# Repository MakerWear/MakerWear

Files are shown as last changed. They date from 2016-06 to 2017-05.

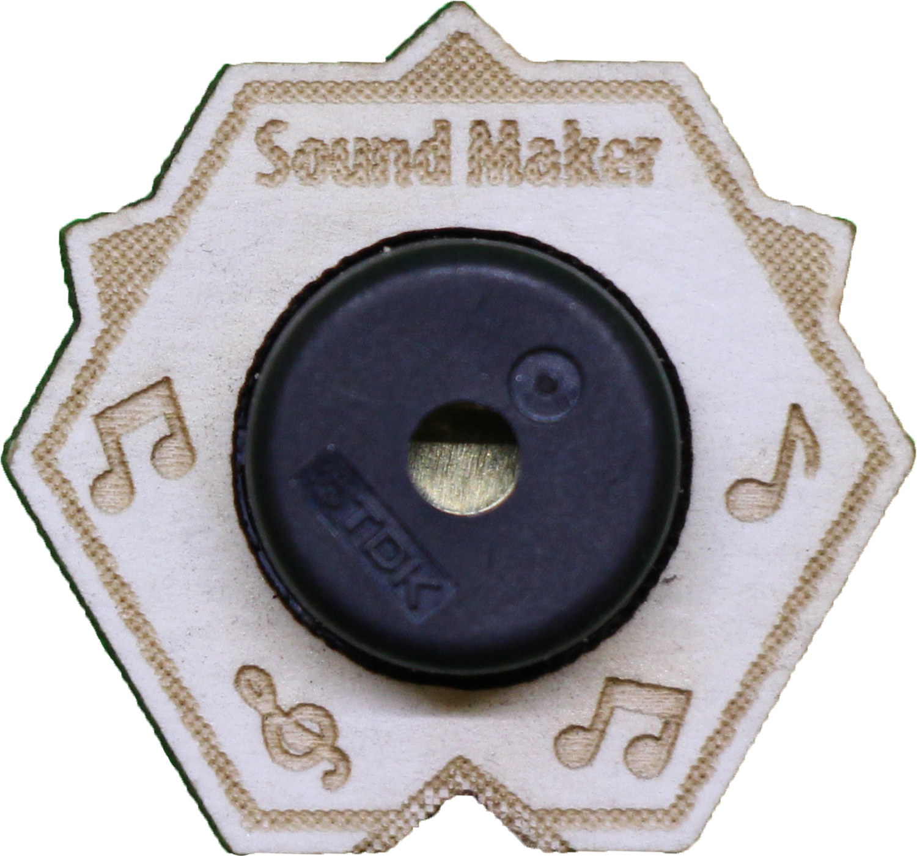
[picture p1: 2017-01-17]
Common/Wiki/images/Action/SoundMaker.png

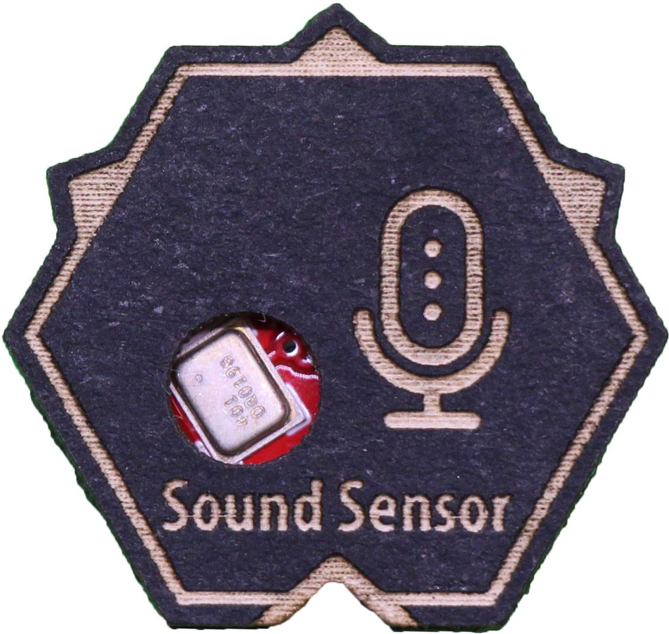
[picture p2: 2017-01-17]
Common/Wiki/images/Sensor/SoundSensor.png

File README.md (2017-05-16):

# MakerWear
MakerWear is a tangible and modular, wearable construction kit for young children that contains two parts: (1) a set of single-function, plug-and-play modules that could be combined to create complex interactive behaviors; (2) magnetic socket meshes that are pre-sewn into clothing that provides an easy method to attach and detach modules to clothes.

This repository contains all of the source files that are required to build or modify MakerWear modules in addition to the socket mesh.

# Repository Organization
For example, take the MultiColor Light as an example. Similar to almost all other modules, the MultiColor Light is a 1x3 module which means that it has one input and three outputs and requires two PCBs to build. The bottom PCB is found here: https://github.com/MakerWear/MakerWear/tree/master/Common/BasePCBs/1x3/Bottom and the Top PCB (along with the rest of the source files that are specifically designed for this module) is found here: https://github.com/MakerWear/MakerWear/tree/master/Modules/Action/MultiColorLight

The ComponentList.xlsx contains all of the components and links to the vendors from which you can buy them. the .brd file (board layout) should always be next the the .sch file (board schematics).

Each module has a microcontroller which could be programmed using an Arduino. the arduino source file is inside the https://github.com/MakerWear/MakerWear/tree/master/Modules/Action/MultiColorLight/ArduinoCodes folder. and finally, there is an illustrator file which is used to cut/etch a piece of colored cardboard (e.g. white, red, black, blue for action, power, sensor and modifier) using a laser cutter.

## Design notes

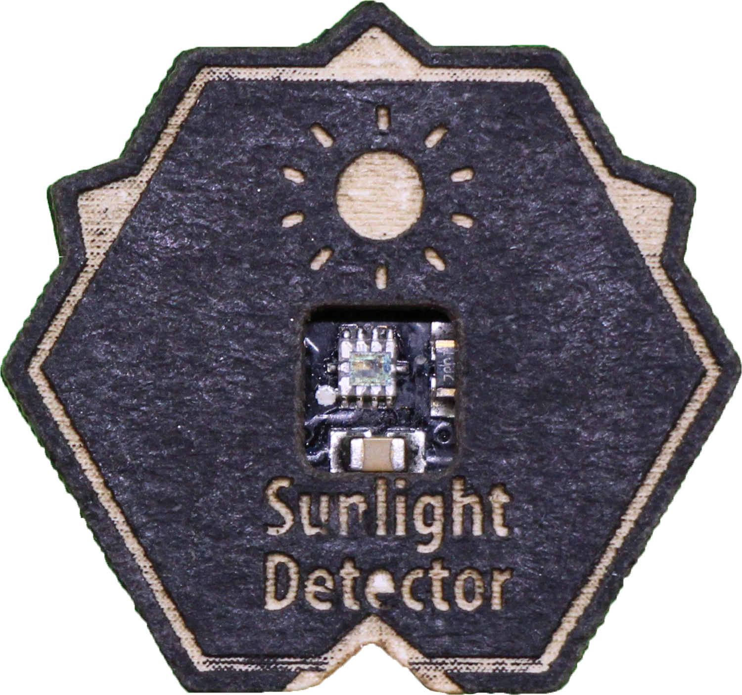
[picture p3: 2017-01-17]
Common/Wiki/images/Sensor/SunlightDetector.png

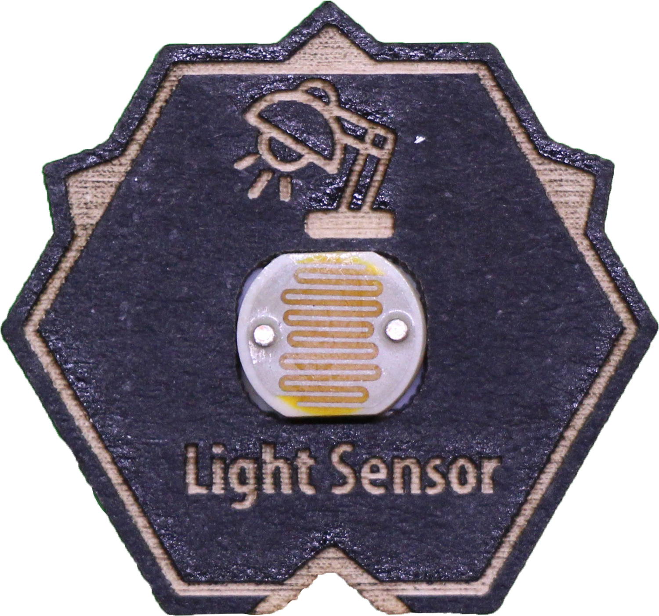
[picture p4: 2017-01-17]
Common/Wiki/images/Sensor/LightSensor.png

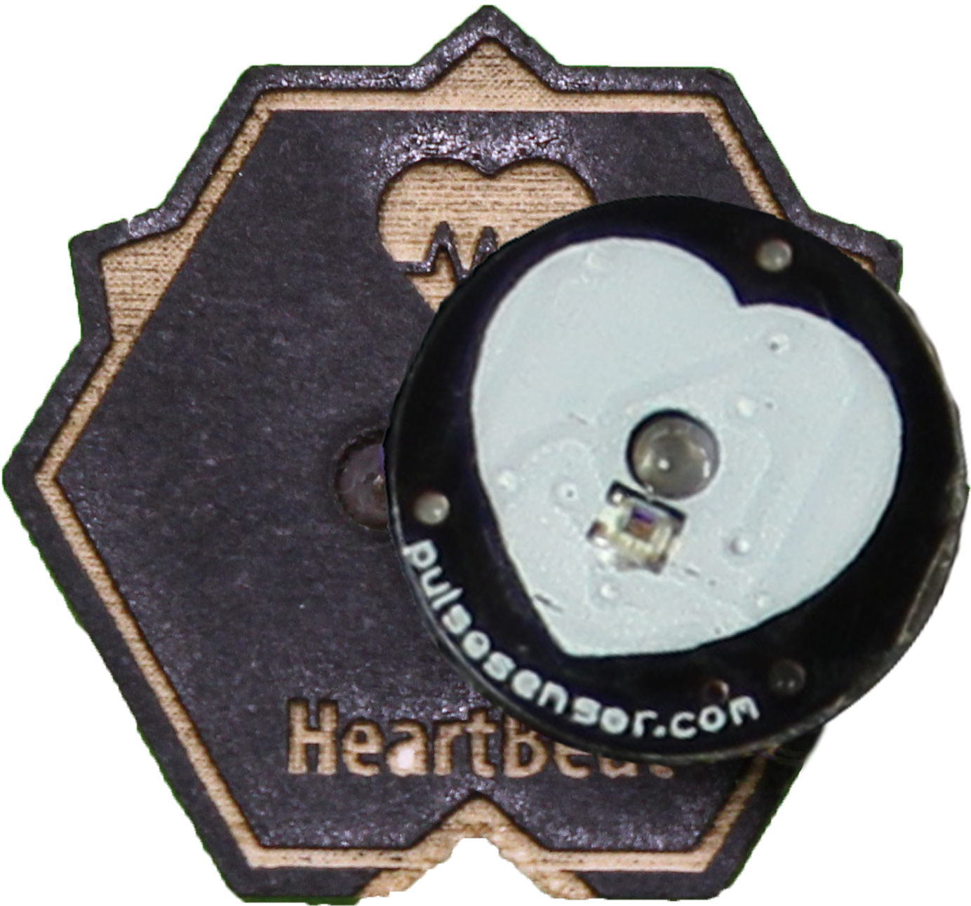
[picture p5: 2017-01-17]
Common/Wiki/images/Sensor/HeartBeatDetector_v3.png

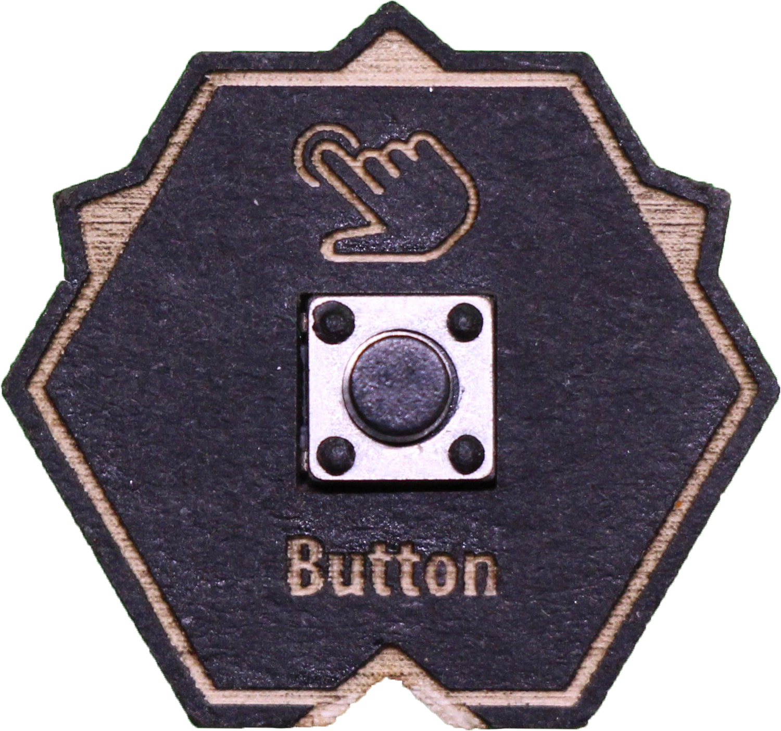
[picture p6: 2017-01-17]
Common/Wiki/images/Sensor/Button.png

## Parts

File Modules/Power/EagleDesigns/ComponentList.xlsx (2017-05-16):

Name | Link | Dimensions | Count | Price
680Ω Resistor | https://www.digikey.com/short/3n01ht | 0603 | 1
SPDT Slide Switch | https://www.sparkfun.com/products/9609 | Through Hole | 1
Small Red LED | https://www.digikey.com/short/3n01cn | 3mm | 1
Shield Finger Contact Spring | http://www.digikey.com/short/3zzmh1 | SMD | 9
3x1 Pin Header | http://www.digikey.com/short/3zzh43 | 2.54mm Pitch | 1

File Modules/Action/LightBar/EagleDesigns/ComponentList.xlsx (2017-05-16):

Name | Link | Dimensions | Count | Price
Rectangular Yellow LED | https://www.digikey.com/short/3n021c | 5x2mm | 2
Rectangular Red LED | https://www.digikey.com/short/3n021z | 5x2mm | 1
Rectangular Green LED | https://www.digikey.com/short/3n0214 | 5x2mm | 1
100Ω SMD Resistor | https://www.digikey.com/short/3n0w5w | 0603 | 4
ATtiny85-20PU | http://www.digikey.com/short/3zphbw | DIP | 1
Shield Finger Contact Spring | http://www.digikey.com/short/3zzmh1 | SMD | 6
1MΩ SMD Resistor | http://www.digikey.com/short/35mdtn | 0603 | 1
4x1 Pin Header | http://www.digikey.com/short/3zzh43 | 2.54mm Pitch | 1

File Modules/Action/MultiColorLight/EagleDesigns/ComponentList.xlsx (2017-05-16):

Name | Link | Dimensions | Count | Price
RGB LED Diffused Common Cathode | https://www.sparkfun.com/products/9264 | 5mm | 1
680Ω SMD Resistor | https://www.digikey.com/short/3n0w0z | 0603 | 1
100Ω SMD Resistor | https://www.digikey.com/short/3n0w5w | 0603 | 2
ATtiny85-20PU | http://www.digikey.com/short/3zphbw | DIP | 1
Shield Finger Contact Spring | http://www.digikey.com/short/3zzmh1 | SMD | 6
1MΩ SMD Resistor | http://www.digikey.com/short/35mdtn | 0603 | 1
4x1 Pin Header | http://www.digikey.com/short/3zzh43 | 2.54mm Pitch | 1

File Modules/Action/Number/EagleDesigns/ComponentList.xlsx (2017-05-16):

Name | Link | Dimensions | Count | Price
7-Segment | http://www.digikey.com/short/3zpcvw | 10x7.3x3.75mm | 1
300Ω SMD Resistor | https://www.digikey.com/short/3n0n83 | 0603 | 1
ATmega328P-AU-ND | http://www.digikey.com/short/3pr0nz | 32TQFP | 1
Shield Finger Contact Spring | http://www.digikey.com/short/3zzmh1 | SMD | 6
1MΩ SMD Resistor | http://www.digikey.com/short/35mdtn | 0603 | 1
4x1 Pin Header | http://www.digikey.com/short/3zzh43 | 2.54mm Pitch | 1

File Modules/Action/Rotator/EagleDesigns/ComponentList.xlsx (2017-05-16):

Name | Link | Dimensions | Count | Price
Nano Servo Motor | https://www.sparkfun.com/products/11882 | 18.6x7.6x15.5mm | 1
ATmega328P-AU-ND | http://www.digikey.com/short/3pr0nz | 32TQFP | 1
Shield Finger Contact Spring | http://www.digikey.com/short/3zzmh1 | SMD | 6
1MΩ SMD Resistor | http://www.digikey.com/short/35mdtn | 0603 | 1
4x1 Pin Header | http://www.digikey.com/short/3zzh43 | 2.54mm Pitch | 1

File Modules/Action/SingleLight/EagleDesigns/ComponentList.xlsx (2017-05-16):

Name | Link | Dimensions | Count | Price
Diffused single-color LED | https://www.sparkfun.com/products/12062 | 5mm | 1
100Ω SMD Resistor | https://www.digikey.com/short/3n0w5w | 0603 | 1
ATtiny85-20PU | http://www.digikey.com/short/3zphbw | DIP | 1
Shield Finger Contact Spring | http://www.digikey.com/short/3zzmh1 | SMD | 6
1MΩ SMD Resistor | http://www.digikey.com/short/35mdtn | 0603 | 1
4x1 Pin Header | http://www.digikey.com/short/3zzh43 | 2.54mm Pitch | 1

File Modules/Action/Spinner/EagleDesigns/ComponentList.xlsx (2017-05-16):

Name | Link | Dimensions | Count | Price
Uxcell DC Motor | https://amzn.com/B00BG8V144 |  | 1
10Ω SMD Resistor | https://www.digikey.com/short/3n0n9h | 0603 | 1
ATtiny85-20PU | http://www.digikey.com/short/3zphbw | DIP | 1
Shield Finger Contact Spring | http://www.digikey.com/short/3zzmh1 | SMD | 6
1MΩ SMD Resistor | http://www.digikey.com/short/35mdtn | 0603 | 1
4x1 Pin Header | http://www.digikey.com/short/3zzh43 | 2.54mm Pitch | 1

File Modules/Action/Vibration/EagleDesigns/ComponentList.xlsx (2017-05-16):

Name | Link | Dimensions | Count | Price
Vibrating Mini Motor Disc | https://www.adafruit.com/product/1201 | 10mm | 1
4.7Ω SMD Resistor | https://www.digikey.com/short/3n0d85 | 0603 | 1
ATtiny85-20PU | http://www.digikey.com/short/3zphbw | DIP | 1
Shield Finger Contact Spring | http://www.digikey.com/short/3zzmh1 | SMD | 6
1MΩ SMD Resistor | http://www.digikey.com/short/35mdtn | 0603 | 1
4x1 Pin Header | http://www.digikey.com/short/3zzh43 | 2.54mm Pitch | 1

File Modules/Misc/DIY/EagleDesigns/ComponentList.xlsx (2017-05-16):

Name | Link | Dimensions | Count | Price
Op-Amp (Rail-to-Rail) | http://www.digikey.com/short/3zp31d | SMD | 1
Shield Finger Contact Spring | http://www.digikey.com/short/3zzmh1 | SMD | 6
4x1 Pin Header | http://www.digikey.com/short/3zzh43 | 2.54mm Pitch | 1
Tiny Breadboard | https://www.adafruit.com/products/2463 | 18x13mm | 1

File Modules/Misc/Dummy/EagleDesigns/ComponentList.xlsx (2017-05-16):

Name | Link | Dimensions | Count | Price
Shield Finger Contact Spring | http://www.digikey.com/short/3zzmh1 | SMD | 6
4x1 Pin Header | http://www.digikey.com/short/3zzh43 | 2.54mm Pitch | 1
3D Printed LEGO Piece

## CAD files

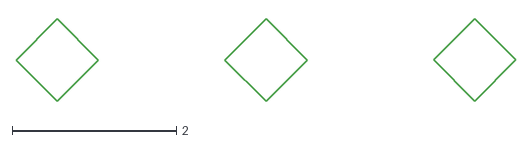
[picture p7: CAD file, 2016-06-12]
Common/BasePCBs/0x6/Bottom/Dimensions/dxf/0x6_bottom_tLayer.dxf
6.08 x 1.00

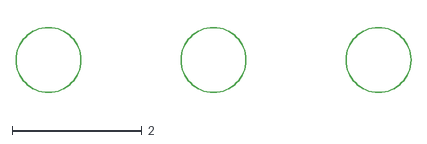
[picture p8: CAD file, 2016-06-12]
Common/BasePCBs/0x6/Top/Dimensions/dxf/0x6_top_pads(holes).dxf
6.08 x 1.00

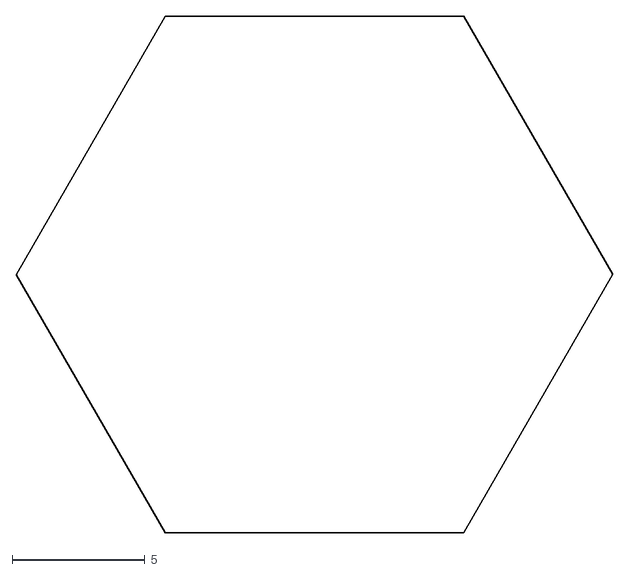
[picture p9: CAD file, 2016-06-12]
Common/BasePCBs/1x3/Bottom/Dimensions/dxf/0x6_bottom_board_outline(a).dxf
22.5 x 19.5

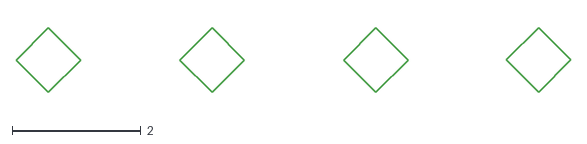
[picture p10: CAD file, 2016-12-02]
Common/BasePCBs/1x3/TopLarge/Dimensions/1x3Top_pads.dxf
8.61 x 1.00

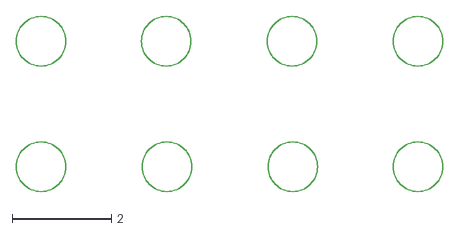
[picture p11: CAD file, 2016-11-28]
Common/BasePCBs/3x3/bottom/Dimensions/dxf/3x3Bottom_pads.dxf
8.61 x 3.53

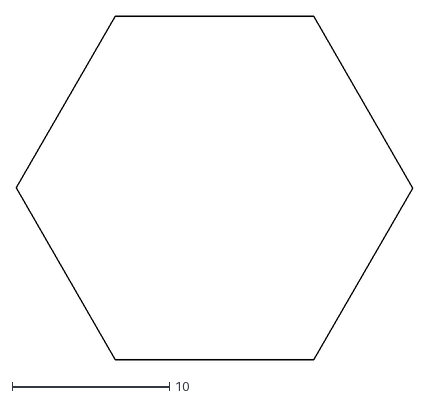
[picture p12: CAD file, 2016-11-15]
Common/BasePCBs/3x3/top/Dimensions/dxf/3x3Top_outline(b).dxf
25.2 x 21.8

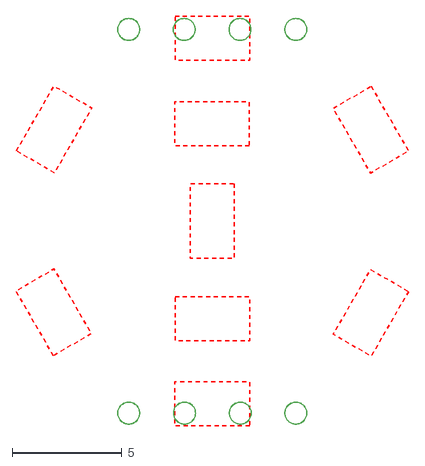
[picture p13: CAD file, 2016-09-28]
Common/BasePCBs/3x3Bottom/Dimensions/placements.dxf
17.9 x 18.7

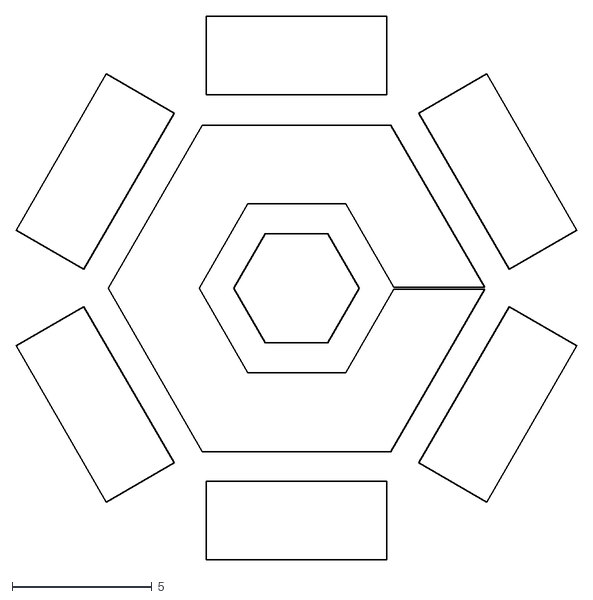
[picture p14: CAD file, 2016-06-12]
Common/BasePCBs/Socket/Dimensions/dxf/socket_bLayer.dxf
20.1 x 19.5

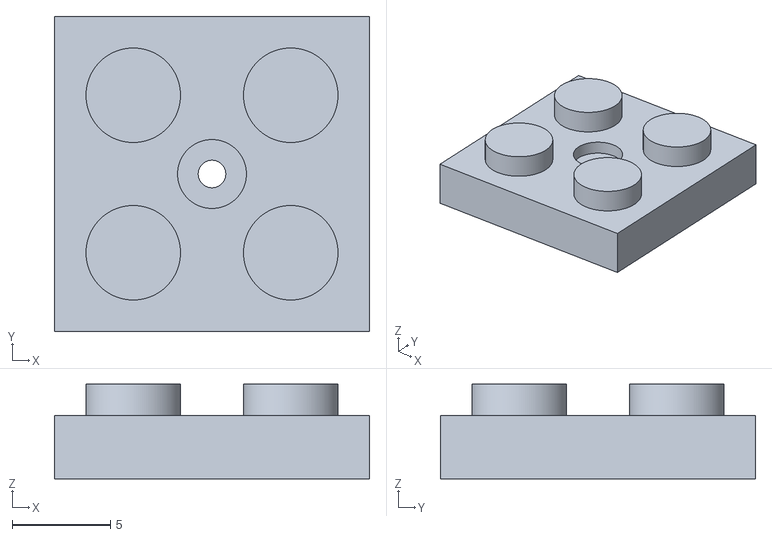
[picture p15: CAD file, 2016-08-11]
Modules/Action/Rotator/3DModels/LegoShaft.stl
16.0 x 16.0 x 4.80

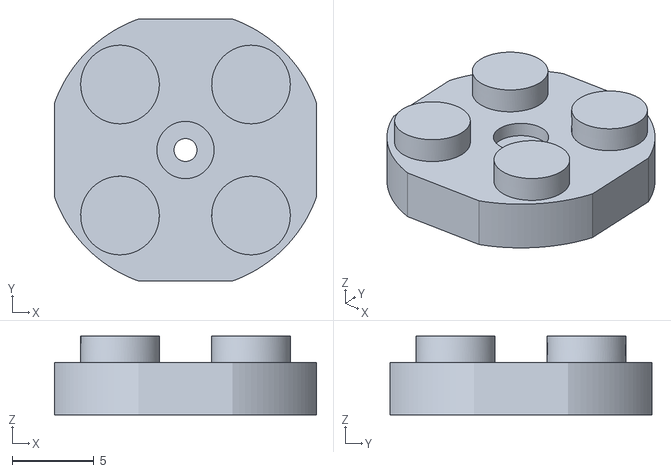
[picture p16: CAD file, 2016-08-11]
Modules/Misc/Dummy/3DModels/DummyLEGO.stl
16.0 x 16.0 x 4.80

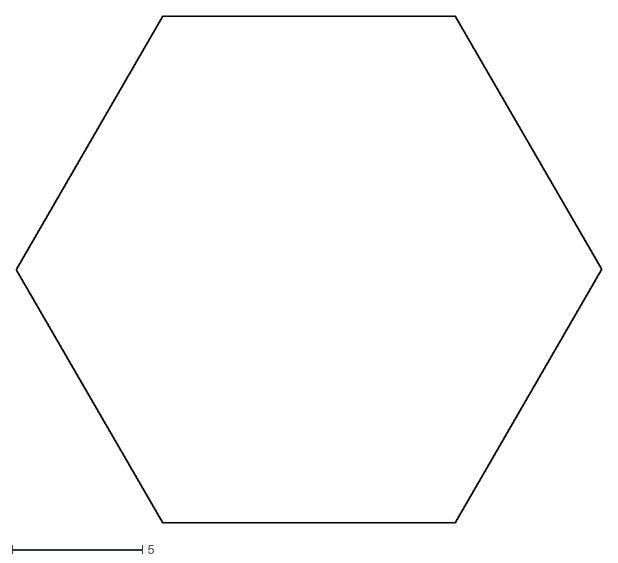
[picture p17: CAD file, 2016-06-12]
Common/BasePCBs/0x6/Bottom/Dimensions/dxf/0x6_bottom_board_outline(a).dxf
22.5 x 19.5

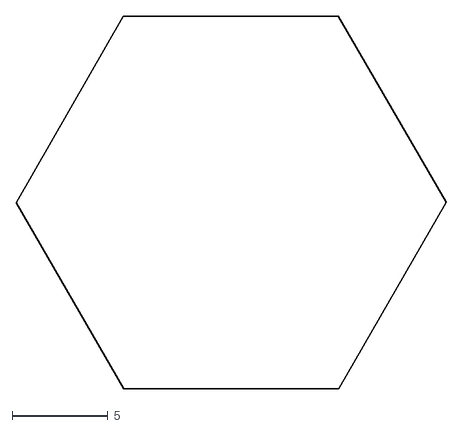
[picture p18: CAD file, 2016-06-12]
Common/BasePCBs/0x6/Top/Dimensions/dxf/0x6_top_board_outline(b).dxf
22.5 x 19.5

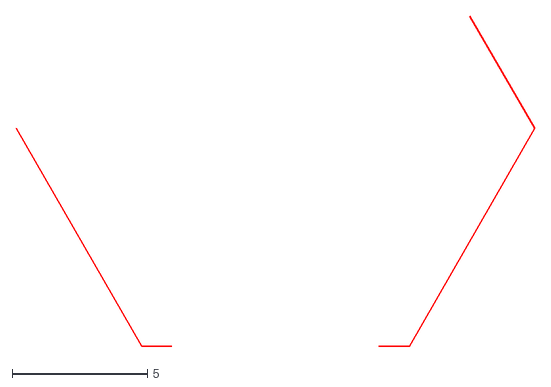
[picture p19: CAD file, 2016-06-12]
Common/BasePCBs/1x3/Bottom/Dimensions/dxf/1x3_bottom_tDoc.dxf
19.2 x 12.2

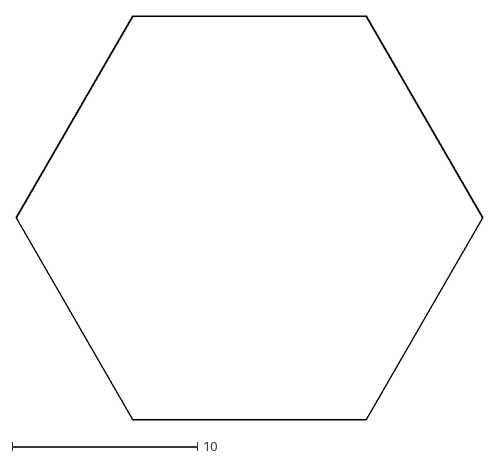
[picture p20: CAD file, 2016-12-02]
Common/BasePCBs/1x3/TopLarge/Dimensions/1x3Top_outline(a).dxf
25.2 x 21.8

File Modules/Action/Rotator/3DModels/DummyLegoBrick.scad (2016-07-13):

/*

 Basic Lego brick builder module for OpenScad by Jorg Janssen 2013 (CC BY-NC 3.0) 
 To use this in your own projects add:

 use <path_to_this_file/lego_brick_builder.scad>
 brick (length, width, height [,smooth]);

 Length and width are in standard lego brick dimensions. 
 Height is in flat brick heights, so for a normal lego brick height = 3.
 Add optional smooth = true for a brick without studs. 
 Use height = 0 to just put studs/knobs on top of other things.

 */
$fn = 150;
 
 // this is it:
brick(2,2,1);


// and this is how it's done:

FLU = 1.6; // Fundamental Lego Unit = 1.6 mm

BRICK_WIDTH = 5*FLU; // basic brick width
BRICK_HEIGHT = 6*FLU; // basic brick height
PLATE_HEIGHT = 2*FLU; // basic plate height
WALL_THICKNESS = FLU; // outer wall of the brick
STUD_RADIUS = 0*FLU; // studs are the small cylinders on top of the brick with the lego logo ('nopje' in Dutch)
STUD_HEIGHT = FLU; 
ANTI_STUD_RADIUS = 0.5*4.07*FLU;  // an anti stud is the hollow cylinder inside bricks that have length > 1 and width > 1
PIN_RADIUS = FLU; // a pin is the small cylinder inside bricks that have length = 1 or width = 1
SUPPORT_THICKNESS = 0.254; // support is the thin surface between anti studs, pins and walls, your printer might not print this thin, try thicker!
EDGE = 0.254; // this is the width and height of the bottom line edge of smooth bricks
CORRECTION = 0.1; // addition to each size, to make sure all parts connect by moving them a little inside each other

module brick(length = 4, width = 2, height = 3, smooth = false){

	// brick shell
	difference(){
		cube(size = [length*BRICK_WIDTH,width*BRICK_WIDTH,height*PLATE_HEIGHT]);
		translate([WALL_THICKNESS,WALL_THICKNESS,-WALL_THICKNESS])
		union(){
			cube(size = [length*BRICK_WIDTH-2*WALL_THICKNESS,width*BRICK_WIDTH-2*WALL_THICKNESS,height*PLATE_HEIGHT]);
			// stud inner holes, radius = pin radius
			if (!smooth) {
			
			}
			// small bottom line edge for smooth bricks
			else {
				translate([-WALL_THICKNESS-CORRECTION,-WALL_THICKNESS-CORRECTION,FLU-CORRECTION]) 
				difference() {
					cube([length*BRICK_WIDTH+2*CORRECTION,width*BRICK_WIDTH+2*CORRECTION,EDGE+CORRECTION]);
					translate([EDGE+CORRECTION,EDGE+CORRECTION,-CORRECTION])
					cube([length*BRICK_WIDTH-2*EDGE,width*BRICK_WIDTH-2*EDGE,EDGE+3*CORRECTION]); 
				}
			}
		}
	}
	// Studs
	if(!smooth){
		translate([STUD_RADIUS+WALL_THICKNESS,STUD_RADIUS+WALL_THICKNESS,height*PLATE_HEIGHT])
		for (y = [0:width-1]){
			for (x = [0:length-1]){
				translate ([x*BRICK_WIDTH,y*BRICK_WIDTH,-CORRECTION])
				difference(){
					cylinder(h=STUD_HEIGHT+CORRECTION, r=STUD_RADIUS);
					// Stud inner holes
					translate([0,0,-CORRECTION])
					cylinder(h=0.5*STUD_HEIGHT+CORRECTION,r=PIN_RADIUS);
				}
				// tech logo - disable this if your printer isn't capable of printing this small
				if ( length > width){
					translate([x*BRICK_WIDTH+0.8,y*BRICK_WIDTH-1.9,STUD_HEIGHT-CORRECTION])
					resize([1.2*1.7,2.2*1.7,0.254+CORRECTION])
					rotate(a=[0,0,90])
					import("tech.stl");
				}
				else {
					translate([x*BRICK_WIDTH-1.9,y*BRICK_WIDTH-0.8,STUD_HEIGHT-CORRECTION])
					resize([2.2*1.7,1.2*1.7,0.254+CORRECTION])
					import("tech.stl");				
				}				
				/* 
				// Alternative 2-square logo
				translate ([x*BRICK_WIDTH+CORRECTION,y*BRICK_WIDTH-CORRECTION,STUD_HEIGHT-CORRECTION])		
				cube([1,1,2*CORRECTION]);
				translate ([x*BRICK_WIDTH-0.9,y*BRICK_WIDTH-0.9,STUD_HEIGHT-CORRECTION])		
				cube([1,1,0.3]);
				*/				
			}
		}
	}
	// Pins x
	if (width == 1 && length > 1) {	
			for (x = [1:length-1]){
				translate([x*BRICK_WIDTH,0.5*BRICK_WIDTH,0])
				cylinder(h=height*PLATE_HEIGHT-WALL_THICKNESS+CORRECTION,r=PIN_RADIUS);
				// Supports
				if (height > 1) {
				translate([x*BRICK_WIDTH-0.5*SUPPORT_THICKNESS,CORRECTION,STUD_HEIGHT])
				cube(size=[SUPPORT_THICKNESS,BRICK_WIDTH-2*CORRECTION,height*PLATE_HEIGHT-STUD_HEIGHT-WALL_THICKNESS+CORRECTION]);
			}
		}
	}
	// Pins y
	if (length == 1 && width > 1) {	
			for (y = [1:width-1]){
			translate([0.5*BRICK_WIDTH,y*BRICK_WIDTH,0])
			cylinder(h=height*PLATE_HEIGHT-WALL_THICKNESS+CORRECTION,r=PIN_RADIUS);
			// Supports
			if (height > 1) {
			translate([CORRECTION,y*BRICK_WIDTH-0.5*SUPPORT_THICKNESS,STUD_HEIGHT])
			cube(size=[BRICK_WIDTH-2*CORRECTION,SUPPORT_THICKNESS,height*PLATE_HEIGHT-STUD_HEIGHT-WALL_THICKNESS+CORRECTION]);}
			
		}
	}
	// Anti Studs
	if (width > 1 && length > 1){
		difference(){
			union(){
				for(y = [1:width-1]){
					for(x = [1:length-1]){
						// anti studs
						translate([x*BRICK_WIDTH,y*BRICK_WIDTH,0])
						cylinder (h=height*PLATE_HEIGHT-WALL_THICKNESS+CORRECTION, r = ANTI_STUD_RADIUS);
						// Supports
						if (height > 1){
							// Support x
							if (x%2 == 0 && (length%2 == 0 || length%4 == 1 && x<length/2 || length%4 == 3 && x>length/2) || x%2 == 1 && (length%4 == 3 && x<length/2 || length%4 == 1 && x>length/2)) {
								translate([BRICK_WIDTH*x-0.5*SUPPORT_THICKNESS,y*BRICK_WIDTH-BRICK_WIDTH+WALL_THICKNESS-CORRECTION,STUD_HEIGHT])
								cube(size=[SUPPORT_THICKNESS,2*BRICK_WIDTH-2*WALL_THICKNESS,height*PLATE_HEIGHT-STUD_HEIGHT-WALL_THICKNESS+CORRECTION]);
							}
							// Supports y							
							if (y%2 == 0 && (width%2 == 0 || width%4 == 1 && y<width/2 || width%4 == 3 && y>width/2) || y%2 == 1 && (width%4 == 3 && y<width/2 || width%4 == 1 && y>width/2)) {
								translate([x*BRICK_WIDTH-BRICK_WIDTH+WALL_THICKNESS-CORRECTION,BRICK_WIDTH*y-0.5*SUPPORT_THICKNESS,STUD_HEIGHT])
								cube(size=[2*BRICK_WIDTH-2*WALL_THICKNESS,SUPPORT_THICKNESS,height*PLATE_HEIGHT-STUD_HEIGHT-WALL_THICKNESS+CORRECTION]);
							}
						}
					}
				}
			}
			union(){
				for(y = [1:width-1]){
					for(x = [1:length-1]){
						// hollow anti studs
						translate([x*BRICK_WIDTH,y*BRICK_WIDTH,-WALL_THICKNESS])
						cylinder (h=height*PLATE_HEIGHT, r = STUD_RADIUS);				
					}
				}
			}
		}		
	}
}
	

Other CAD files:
Common/BasePCBs/3x3/bottom/Dimensions/dxf/3x3Bottom_contacts.dxf
Common/BasePCBs/3x3/top/Dimensions/dxf/3x3Top_outline(a).dxf
Common/BasePCBs/3x3Bottom/Dimensions/outline_b.dxf
Common/BasePCBs/Socket/Dimensions/dxf/socket_board_outline(a).dxf
Modules/Action/Rotator/3DModels/LegoShaft.scad
Common/BasePCBs/0x6/Bottom/Dimensions/dxf/0x6_bottom_bDoc.dxf
Common/BasePCBs/0x6/Bottom/Dimensions/dxf/0x6_bottom_bLayer.dxf
Common/BasePCBs/0x6/Bottom/Dimensions/dxf/0x6_bottom_board_outline(b).dxf
Common/BasePCBs/0x6/Bottom/Dimensions/dxf/0x6_bottom_tPlace.dxf
Common/BasePCBs/0x6/Top/Dimensions/dxf/0x6_top_board_outline(a).dxf
Common/BasePCBs/1x3/Bottom/Dimensions/dxf/0x6_bottom_board_outline(b).dxf
Common/BasePCBs/1x3/Bottom/Dimensions/dxf/1x3_bottom_bDoc.dxf
Common/BasePCBs/1x3/Bottom/Dimensions/dxf/1x3_bottom_bLayer (b).dxf
Common/BasePCBs/1x3/Bottom/Dimensions/dxf/1x3_bottom_bLayer (c).dxf
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

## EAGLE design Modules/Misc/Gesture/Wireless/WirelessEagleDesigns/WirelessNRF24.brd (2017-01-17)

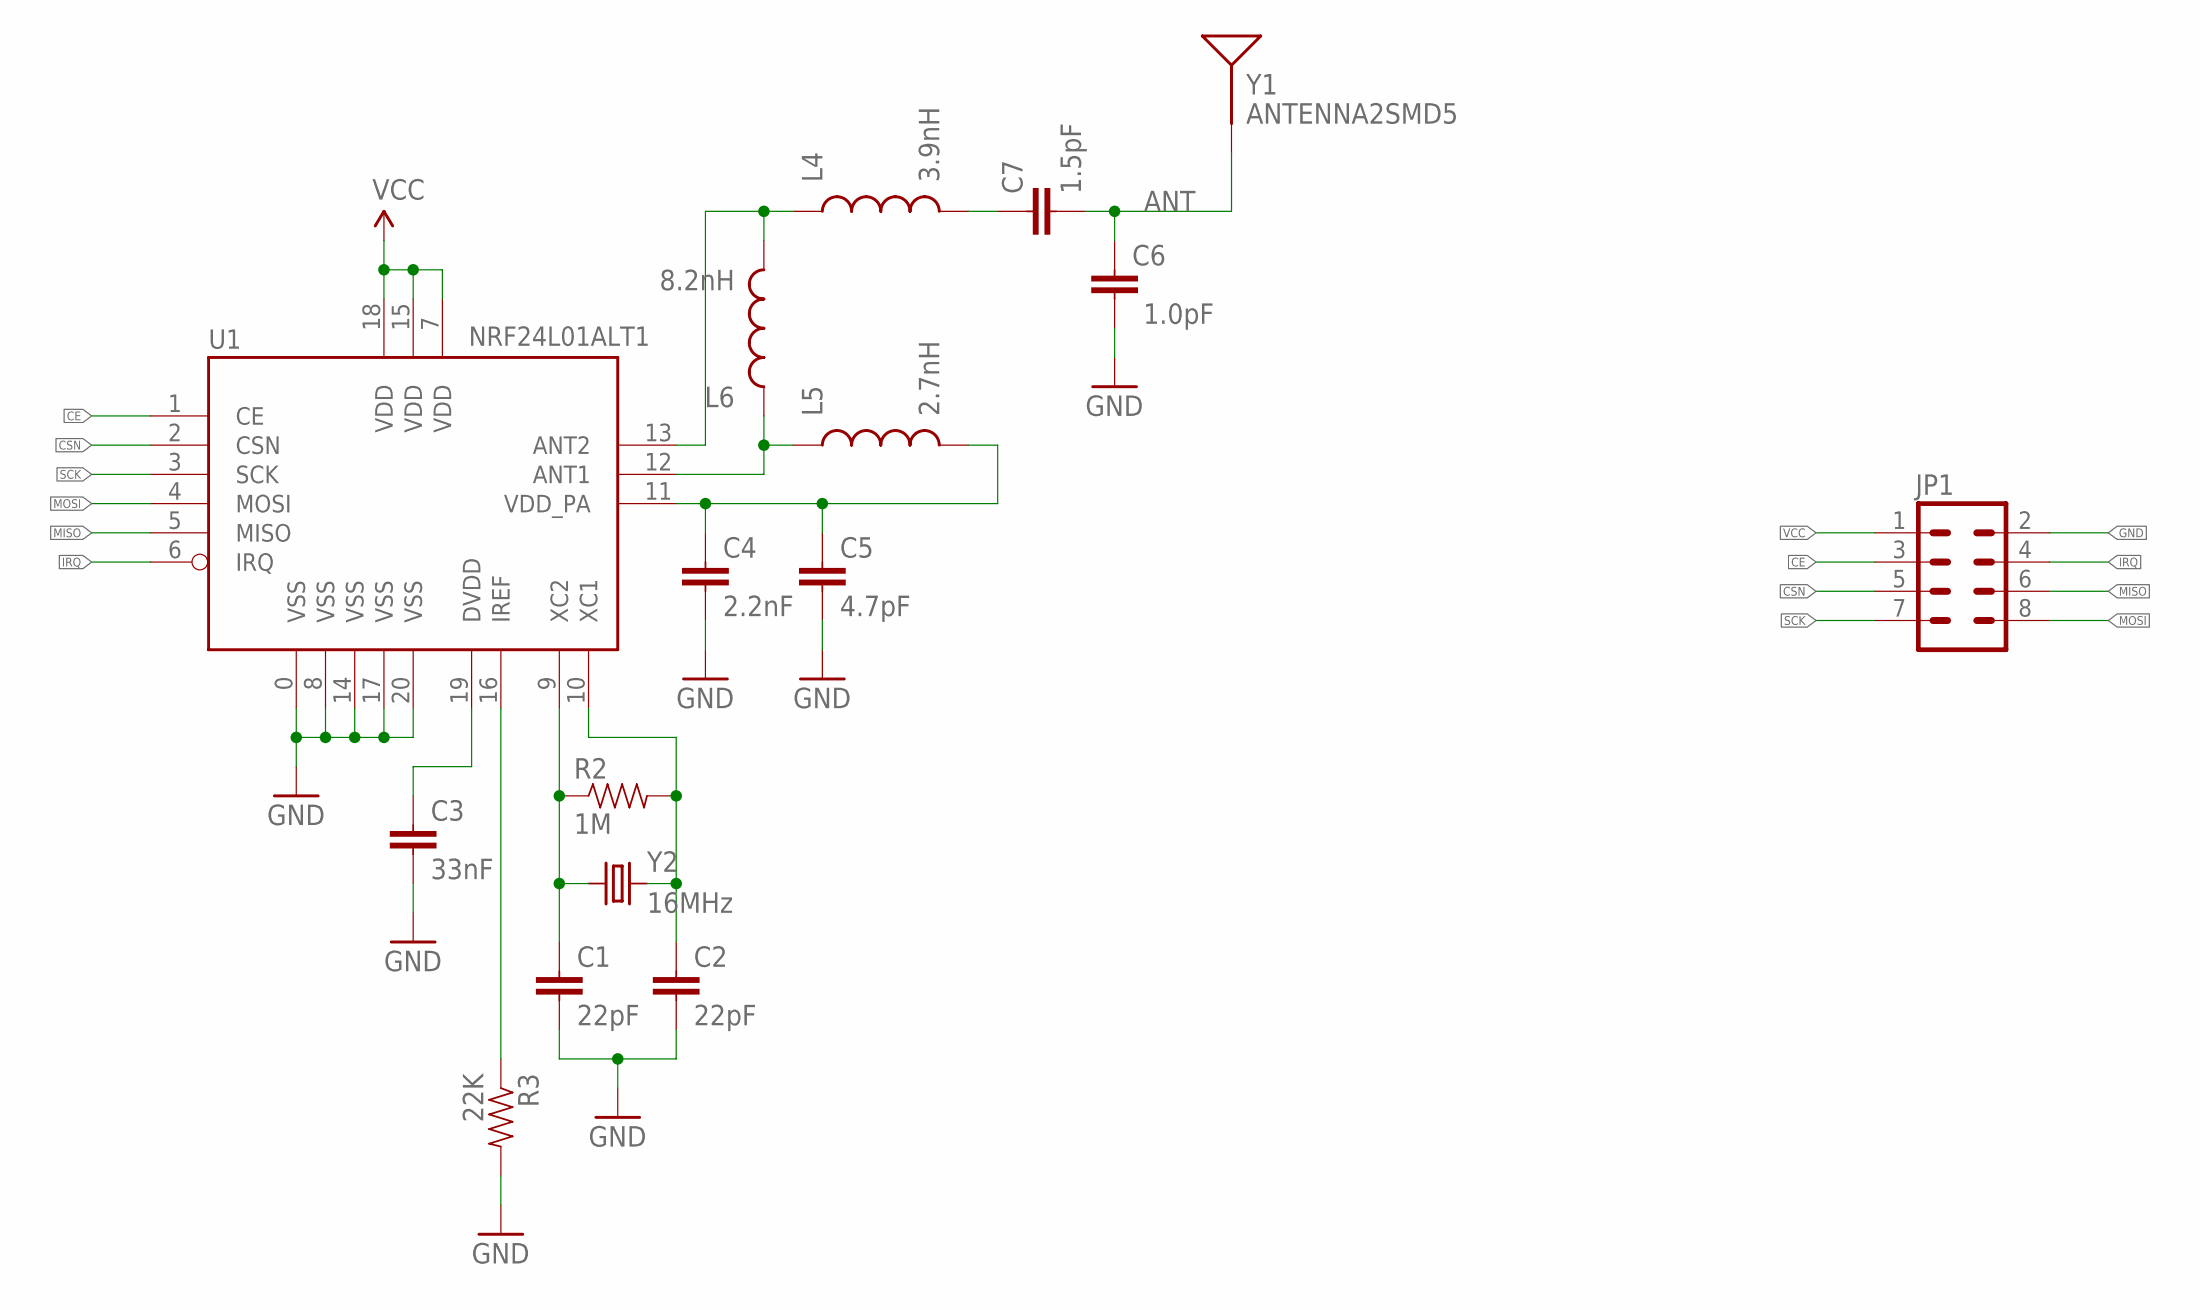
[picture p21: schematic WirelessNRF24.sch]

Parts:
C1, C2: 22pF; 0603-CAP
C3: 33nF; 0603-CAP
C4: 2.2nF; 0603-CAP
C5: 4.7pF; 0603-CAP
C6: 1.0pF; 0603-CAP
C7: 1.5pF; 0603-CAP
JP1: M04X2_0.05"
L4: 3.9nH; 0603
L5: 2.7nH; 0603
L6: 8.2nH; 0603
R2: 1M; 0603-RES
R3: 22K; 0603-RES
U1: NRF24L01ALT1; QFN20_ALT1
Y1: ANTENNA2SMD5; ANTENNA-CHIP5
Y2: 16MHz; CRYSTAL-TXC-7A

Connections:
ANT: C6.2, C7.2, Y1.FEED
CE: JP1.3, U1.1 (CE)
CSN: JP1.5, U1.2 (CSN)
GND: C1.2, C2.2, C3.2, C4.2, C5.2, C6.1, JP1.2, R3.2, U1.0 (VSS), U1.8 (VSS), U1.14 (VSS), U1.17 (VSS), U1.20 (VSS)
IRQ: JP1.4, U1.6 (IRQ)
MISO: JP1.6, U1.5 (MISO)
MOSI: JP1.8, U1.4 (MOSI)
unnamed: C1.1, R2.1, U1.9 (XC2), Y2.P$1 (1)
unnamed: C2.1, R2.2, U1.10 (XC1), Y2.P$2 (2)
unnamed: L5.1, L6.1, U1.12 (ANT1)
unnamed: R3.1, U1.16 (IREF)
unnamed: C3.1, U1.19 (DVDD)
unnamed: L4.1, L6.2, U1.13 (ANT2)
unnamed: C4.1, C5.1, L5.2, U1.11 (VDD_PA)
unnamed: C7.1, L4.2
SCK: JP1.7, U1.3 (SCK)
VCC: JP1.1, U1.7 (VDD), U1.15 (VDD), U1.18 (VDD)

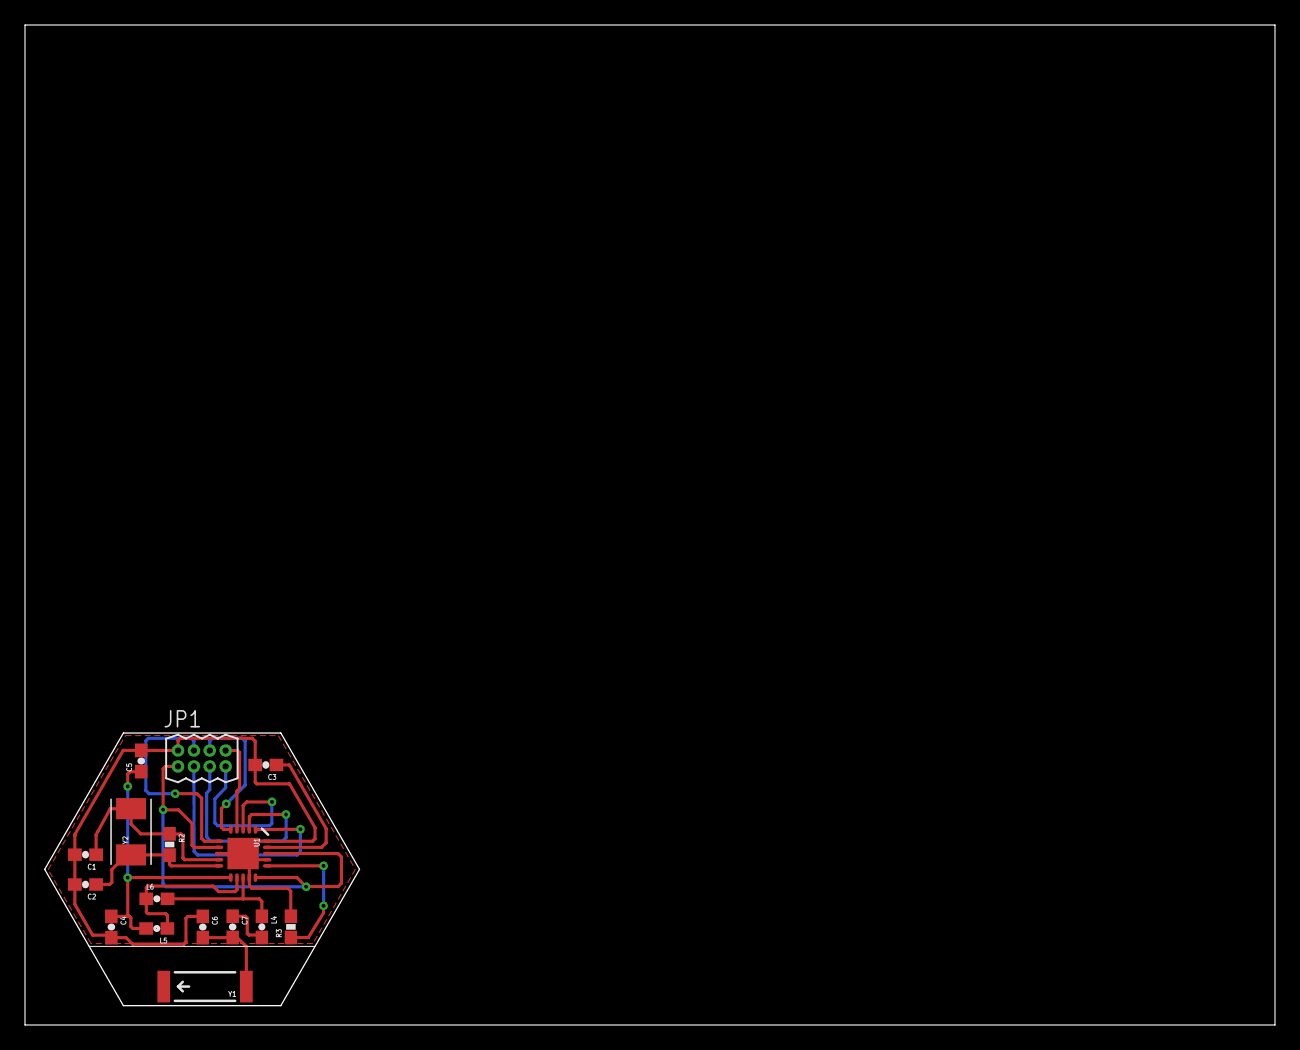
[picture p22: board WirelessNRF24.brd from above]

Board: 2 copper layers, 100.0 x 80.0 mm, 16 parts (0 on the bottom side), 17 nets.

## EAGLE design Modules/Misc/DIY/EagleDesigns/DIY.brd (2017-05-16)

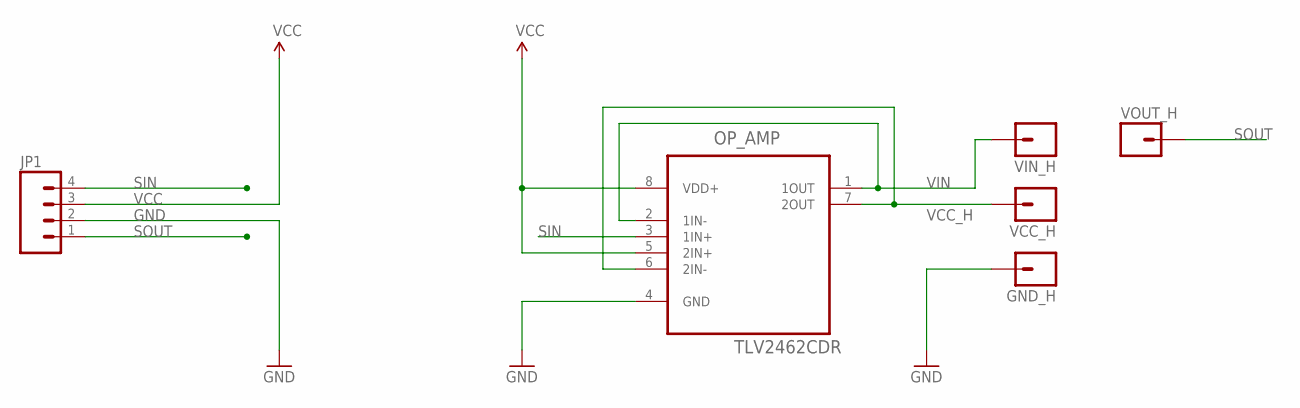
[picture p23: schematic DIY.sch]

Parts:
GND_H: M01PTH; 1X01
JP1: M04PTH; 1X04
OP_AMP: TLV2462CDR; SOIC127P600X175-8N
VCC_H: M01PTH; 1X01
VIN_H: M01PTH; 1X01
VOUT_H: M01PTH; 1X01

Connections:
GND: GND_H.1, JP1.2, OP_AMP.4 (GND)
SIN: JP1.4, OP_AMP.3 (1IN+)
SOUT: JP1.1, VOUT_H.1
VCC: JP1.3, OP_AMP.5 (2IN+), OP_AMP.8 (VDD+)
VCC_H: OP_AMP.6 (2IN-), OP_AMP.7 (2OUT), VCC_H.1
VIN: OP_AMP.1 (1OUT), OP_AMP.2 (1IN-), VIN_H.1

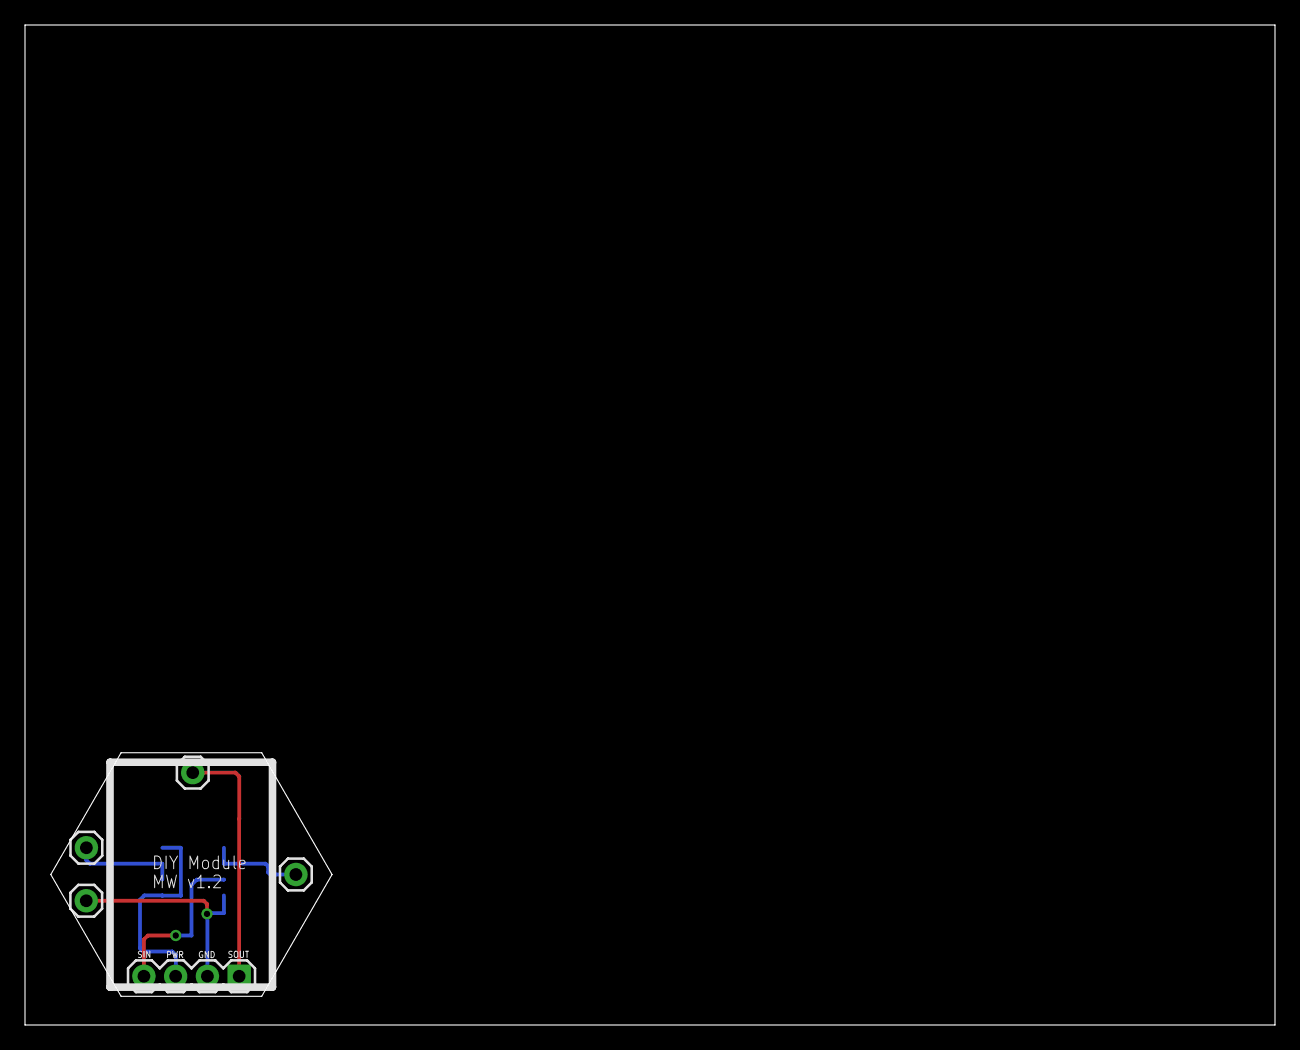
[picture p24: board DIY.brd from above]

Board: 2 copper layers, 100.0 x 80.0 mm, 6 parts (1 on the bottom side), 6 nets.

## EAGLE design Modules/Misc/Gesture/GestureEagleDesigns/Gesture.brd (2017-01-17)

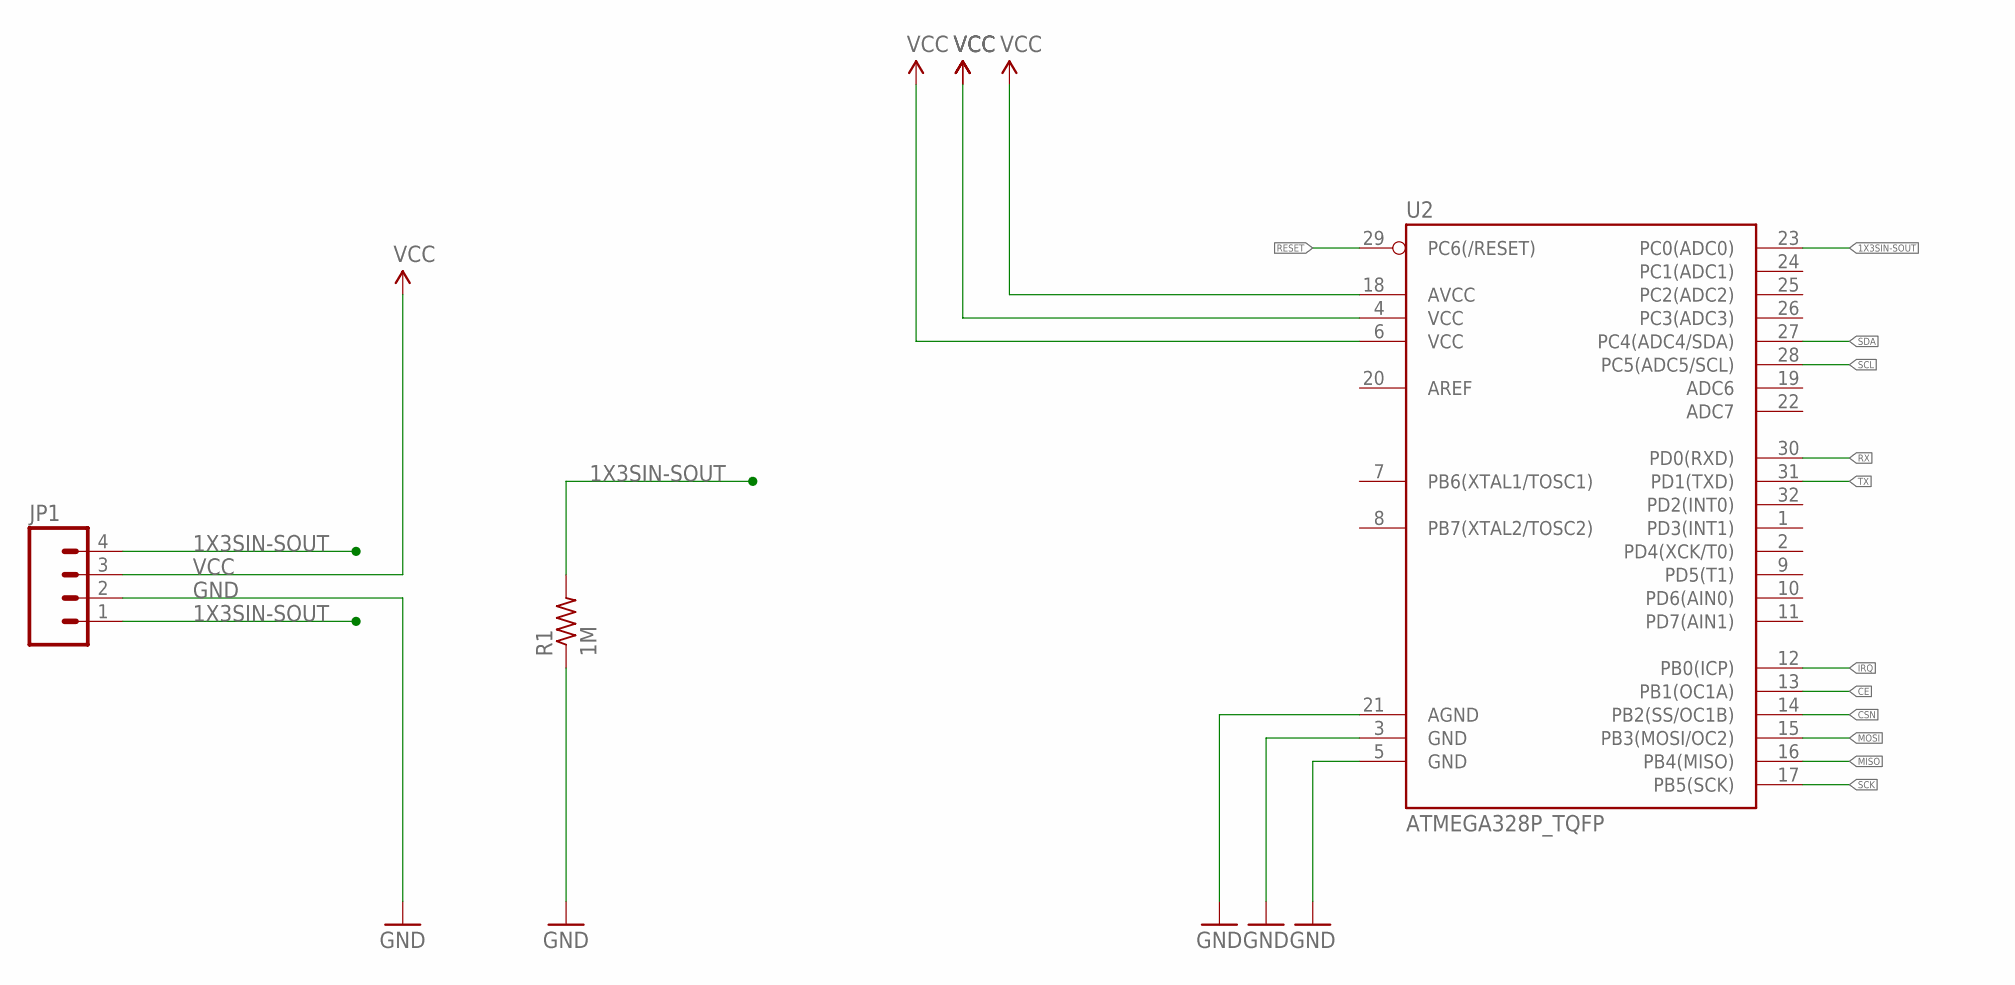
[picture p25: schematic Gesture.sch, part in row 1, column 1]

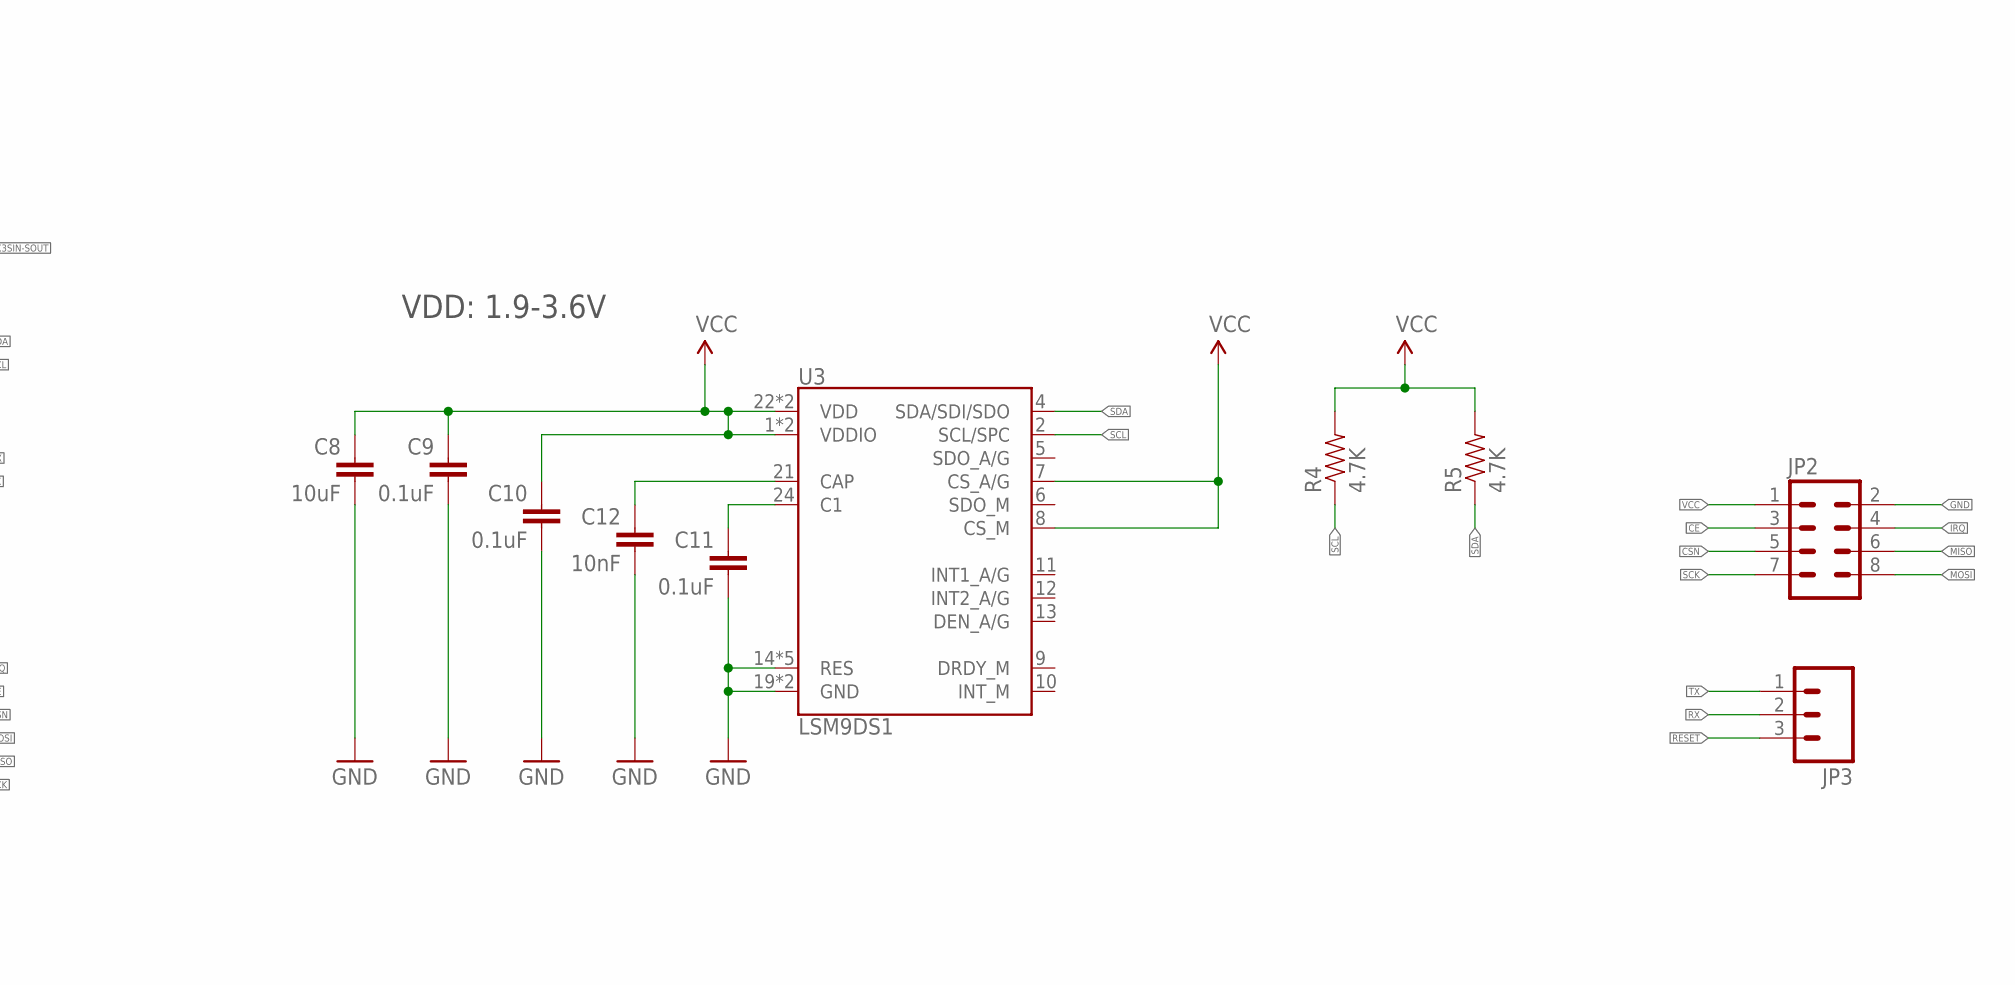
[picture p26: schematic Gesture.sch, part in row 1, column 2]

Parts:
C8: 10uF; 0603-CAP
C9, C10, C11: 0.1uF; 0603-CAP
C12: 10nF; 0603-CAP
JP1: M04PTH; 1X04
JP2: M04X2_0.05"
JP3: M03PTH; 1X03
R1: 1M; R0603
R4, R5: 4.7K; 0603-RES
U2: ATMEGA328P_TQFP; TQFP32-08
U3: LSM9DS1; LGA24-8X4

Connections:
1X3SIN-SOUT: JP1.1, JP1.4, R1.2, U2.23 (PC0(ADC0))
CE: JP2.3, U2.13 (PB1(OC1A))
CSN: JP2.5, U2.14 (PB2(SS/OC1B))
GND: C8.2, C9.2, C10.2, C11.2, C12.2, JP1.2, JP2.2, R1.1, U2.3 (GND), U2.5 (GND), U2.21 (AGND), U3.14 (RES), U3.15 (RES), U3.16 (RES), U3.17 (RES), U3.18 (RES), U3.19 (GND), U3.20 (GND)
IRQ: JP2.4, U2.12 (PB0(ICP))
MISO: JP2.6, U2.16 (PB4(MISO))
MOSI: JP2.8, U2.15 (PB3(MOSI/OC2))
unnamed: C12.1, U3.21 (CAP)
unnamed: C11.1, U3.24 (C1)
RESET: JP3.3, U2.29 (PC6(/RESET))
RX: JP3.2, U2.30 (PD0(RXD))
SCK: JP2.7, U2.17 (PB5(SCK))
SCL: R4.1, U2.28 (PC5(ADC5/SCL)), U3.2 (SCL/SPC)
SDA: R5.1, U2.27 (PC4(ADC4/SDA)), U3.4 (SDA/SDI/SDO)
TX: JP3.1, U2.31 (PD1(TXD))
VCC: C8.1, C9.1, C10.1, JP1.3, JP2.1, R4.2, R5.2, U2.4 (VCC), U2.6 (VCC), U2.18 (AVCC), U3.1 (VDDIO), U3.3 (VDDIO), U3.7 (CS_A/G), U3.8 (CS_M), U3.22 (VDD), U3.23 (VDD)

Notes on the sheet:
VDD: 1.9-3.6V

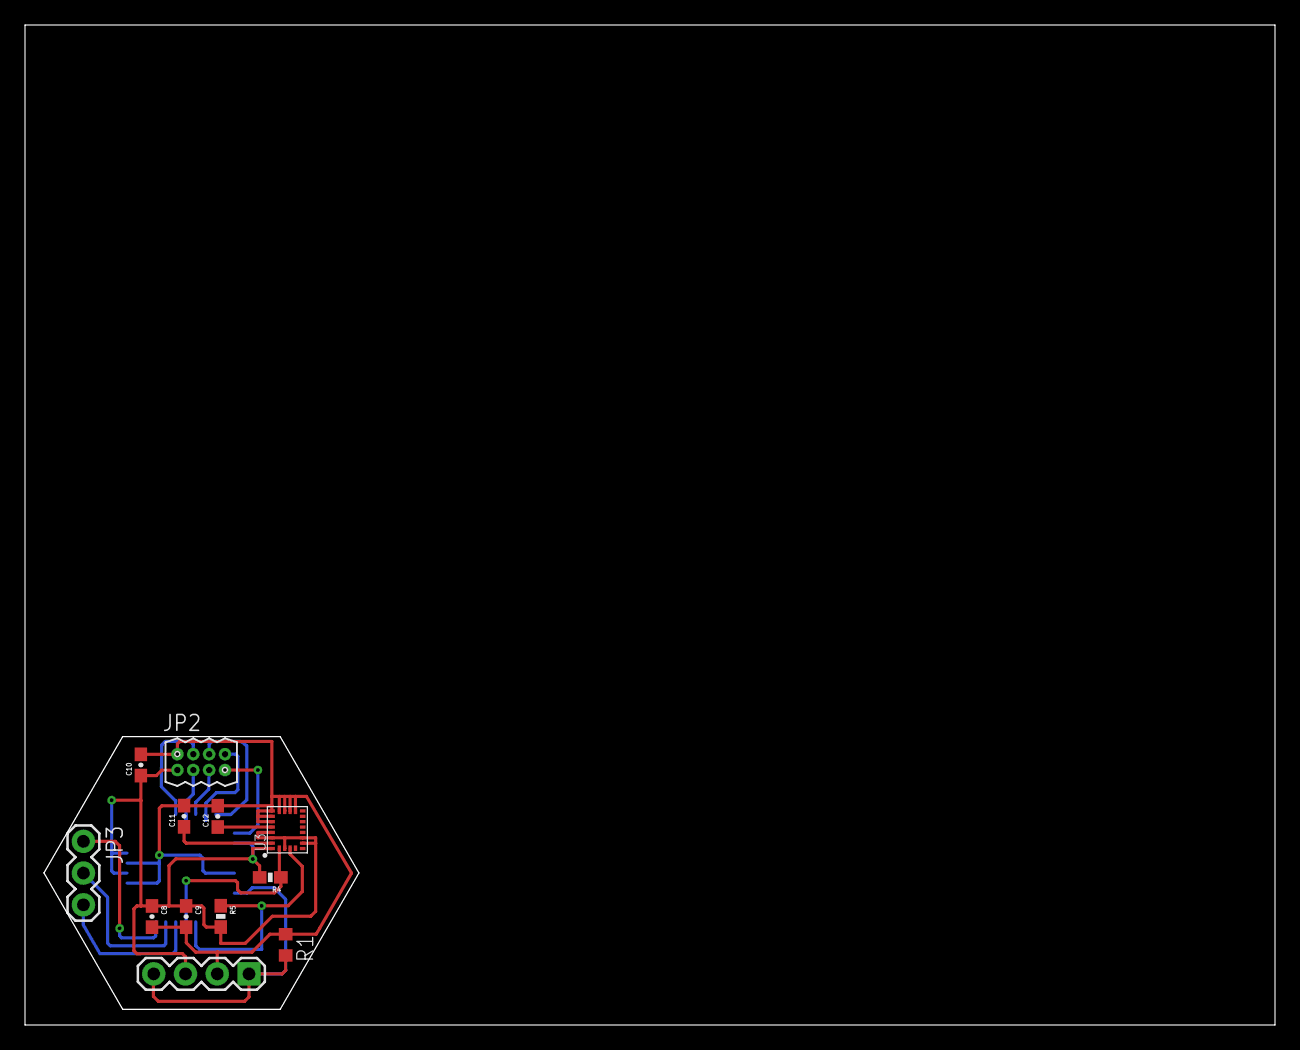
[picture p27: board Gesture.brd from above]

Board: 2 copper layers, 100.0 x 80.0 mm, 13 parts (1 on the bottom side), 16 nets.

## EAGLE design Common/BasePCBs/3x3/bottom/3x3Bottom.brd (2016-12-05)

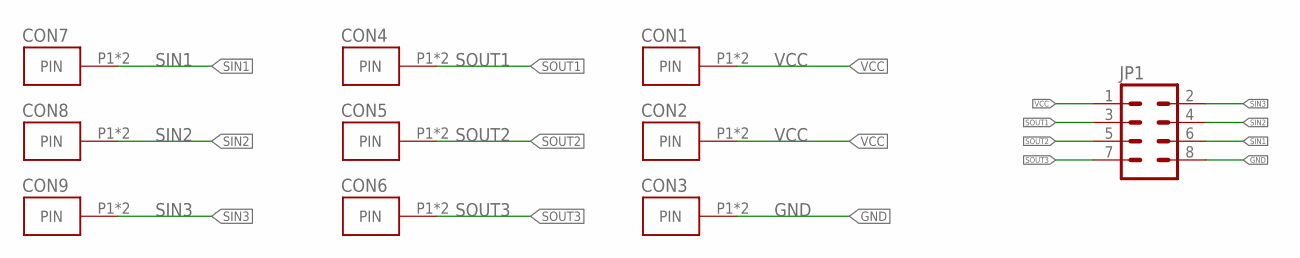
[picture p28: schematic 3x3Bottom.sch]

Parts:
CON1, CON2, CON3, CON4, CON5, CON6, CON7, CON8, CON9: SHIELD_FINGER0820; SHIELD_FINGER_PKG
JP1: M04X2_0.1"; M04X2_0.1"_PADS

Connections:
GND: CON3.P1, CON3.P2, JP1.8
SIN1: CON7.P1, CON7.P2, JP1.6
SIN2: CON8.P1, CON8.P2, JP1.4
SIN3: CON9.P1, CON9.P2, JP1.2
SOUT1: CON4.P1, CON4.P2, JP1.3
SOUT2: CON5.P1, CON5.P2, JP1.5
SOUT3: CON6.P1, CON6.P2, JP1.7
VCC: CON1.P1, CON1.P2, CON2.P1, CON2.P2, JP1.1

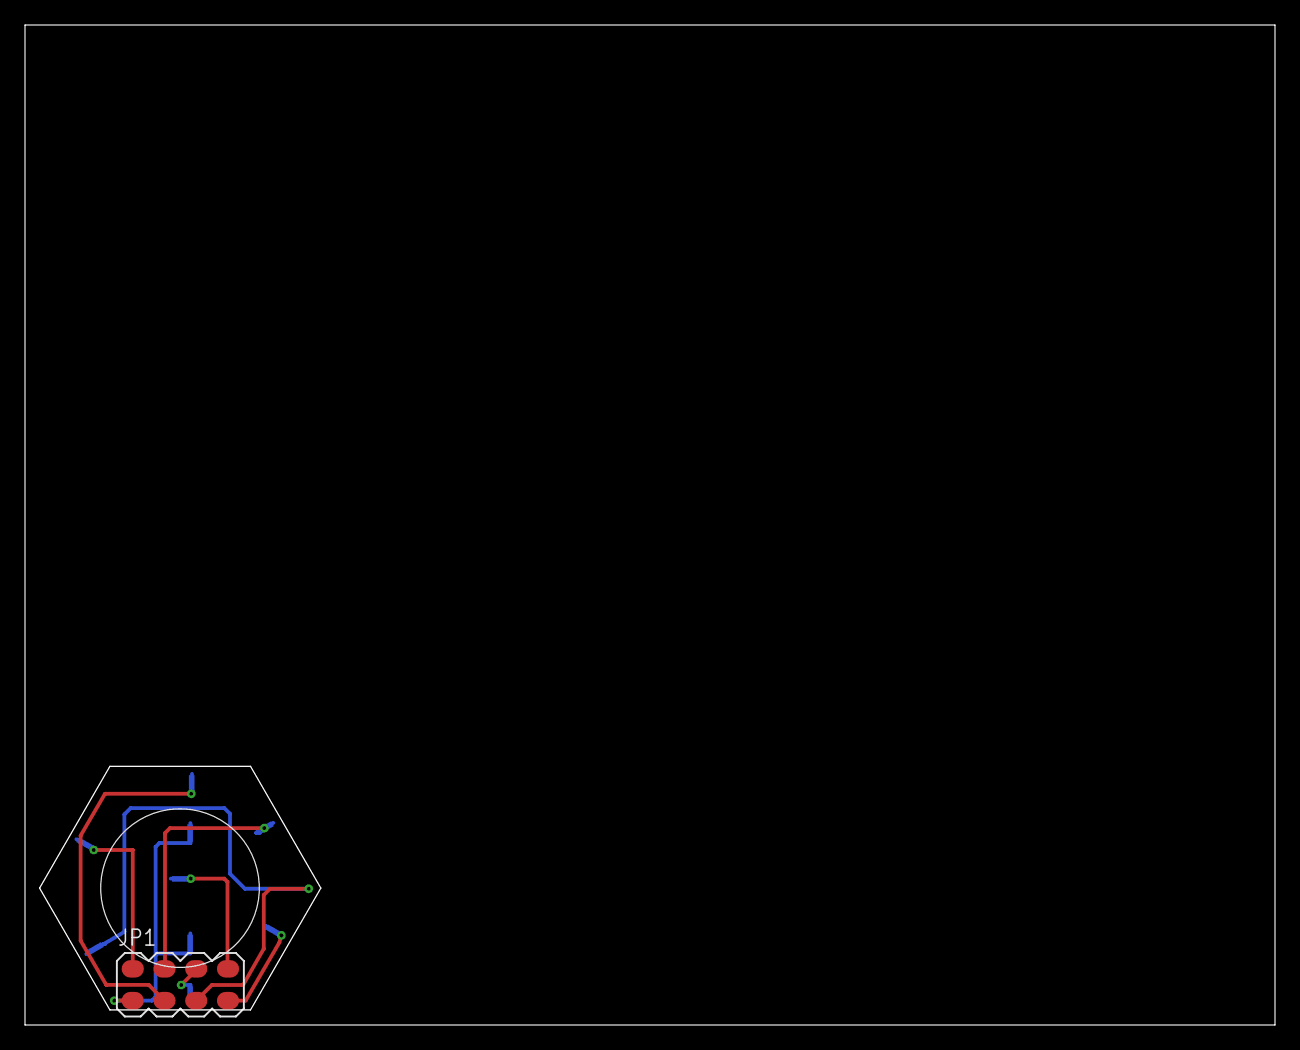
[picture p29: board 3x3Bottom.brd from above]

Board: 2 copper layers, 100.0 x 80.0 mm, 10 parts (0 on the bottom side), 8 nets.

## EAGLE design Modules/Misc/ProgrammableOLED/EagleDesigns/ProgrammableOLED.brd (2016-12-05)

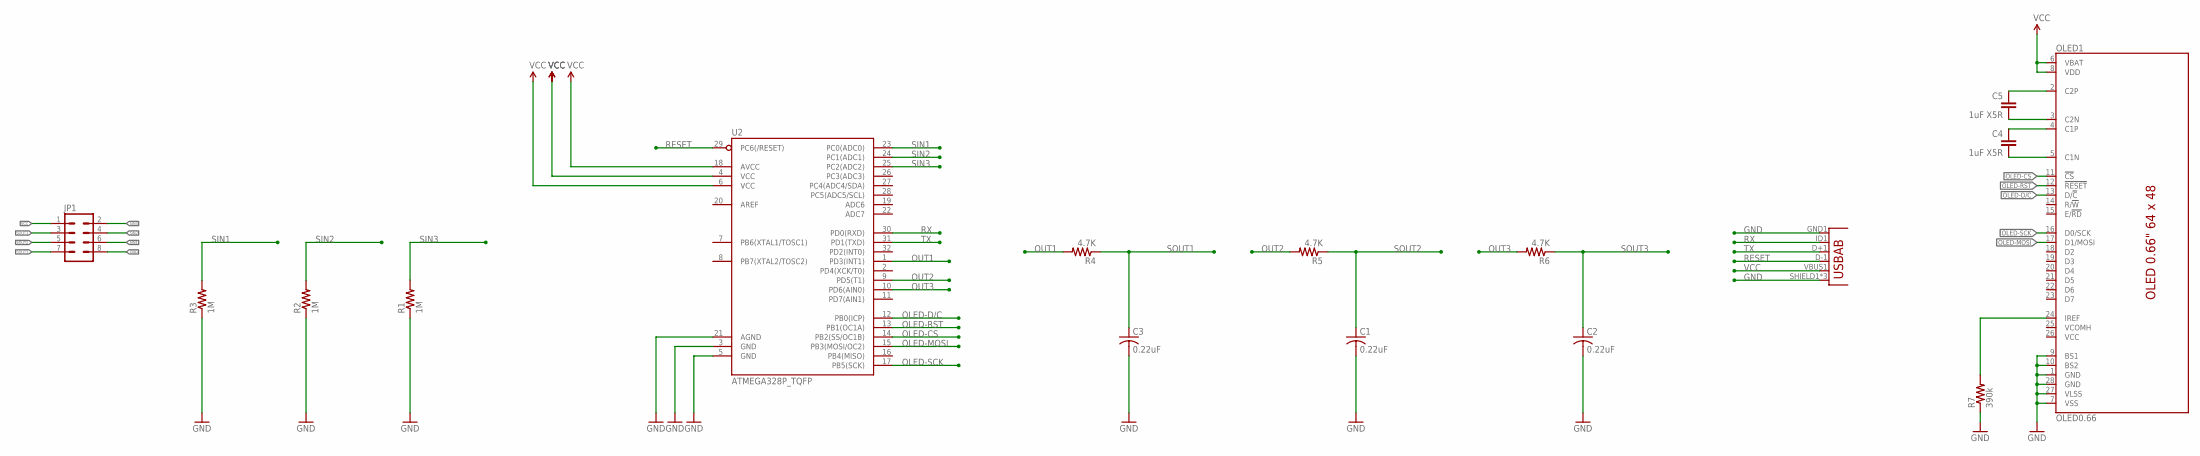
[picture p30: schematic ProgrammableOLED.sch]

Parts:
C1, C2, C3: 0.22uF; C0603
C4, C5: 1uF X5R; 0805
JP1: M04X2; 2X4
JP5: USB-ABCONN-11794; USB-AB-MICRO-SMD_V03
OLED1: OLED0.66; OLED-0.66-64X48
R1, R2, R3: 1M; R0603
R4, R5, R6: 4.7K; R0603
R7: 390k; 0603-RES
U2: ATMEGA328P_TQFP; TQFP32-08

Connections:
C1N: C4.2, OLED1.5 (C1N)
C1P: C4.1, OLED1.4 (C1P)
C2N: C5.2, OLED1.3 (C2N)
C2P: C5.1, OLED1.2 (C2P)
GND: C1.2, C2.2, C3.2, JP1.8, JP5.GND1 (GND), JP5.SHIELD1 (SHIELD), JP5.SHIELD2 (SHIELD), JP5.SHIELD3 (SHIELD), OLED1.1 (GND), OLED1.7 (VSS), OLED1.9 (BS1), OLED1.10 (BS2), OLED1.27 (VLSS), OLED1.28 (GND), R1.1, R2.1, R3.1, R7.1, U2.3 (GND), U2.5 (GND), U2.21 (AGND)
IREF: OLED1.24 (IREF), R7.2
OLED-CS: OLED1.11 (!CS!), U2.14 (PB2(SS/OC1B))
OLED-D/C: OLED1.13 (D/!C!), U2.12 (PB0(ICP))
OLED-MOSI: OLED1.17 (D1/MOSI), U2.15 (PB3(MOSI/OC2))
OLED-RST: OLED1.12 (!RESET!), U2.13 (PB1(OC1A))
OLED-SCK: OLED1.16 (D0/SCK), U2.17 (PB5(SCK))
OUT1: R4.2, U2.1 (PD3(INT1))
OUT2: R5.2, U2.9 (PD5(T1))
OUT3: R6.2, U2.10 (PD6(AIN0))
RESET: JP5.D-1 (D-), U2.29 (PC6(/RESET))
RX: JP5.ID1 (USBID), U2.30 (PD0(RXD))
SIN1: JP1.6, R3.2, U2.23 (PC0(ADC0))
SIN2: JP1.4, R2.2, U2.24 (PC1(ADC1))
SIN3: JP1.2, R1.2, U2.25 (PC2(ADC2))
SOUT1: C3.1, JP1.3, R4.1
SOUT2: C1.1, JP1.5, R5.1
SOUT3: C2.1, JP1.7, R6.1
TX: JP5.D+1 (D+), U2.31 (PD1(TXD))
VCC: JP1.1, JP5.VBUS1 (VBUS), OLED1.6 (VBAT), OLED1.8 (VDD), U2.4 (VCC), U2.6 (VCC), U2.18 (AVCC)

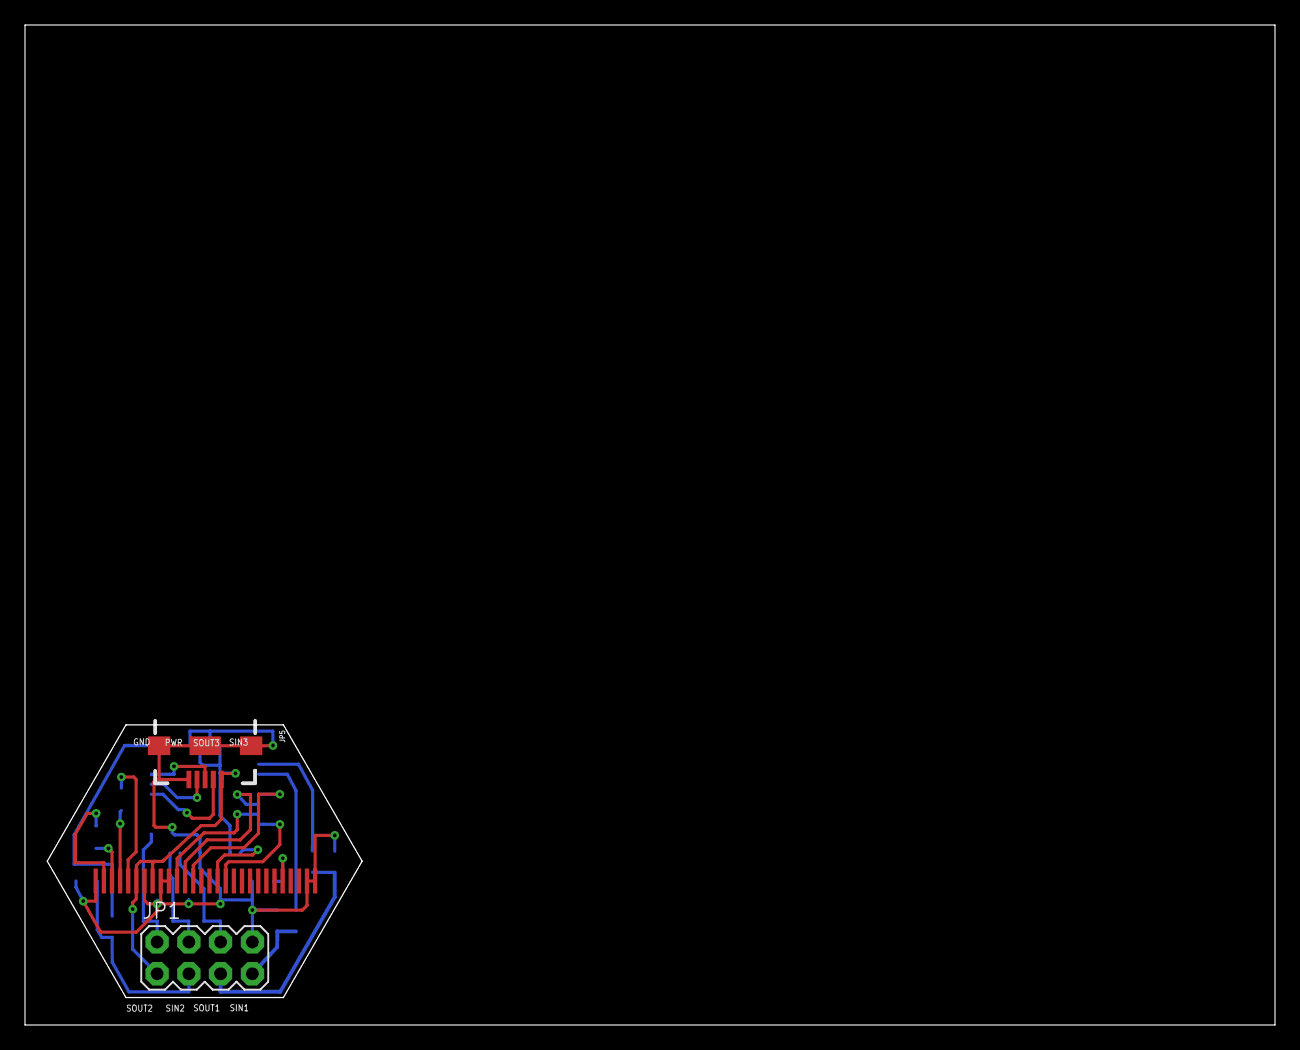
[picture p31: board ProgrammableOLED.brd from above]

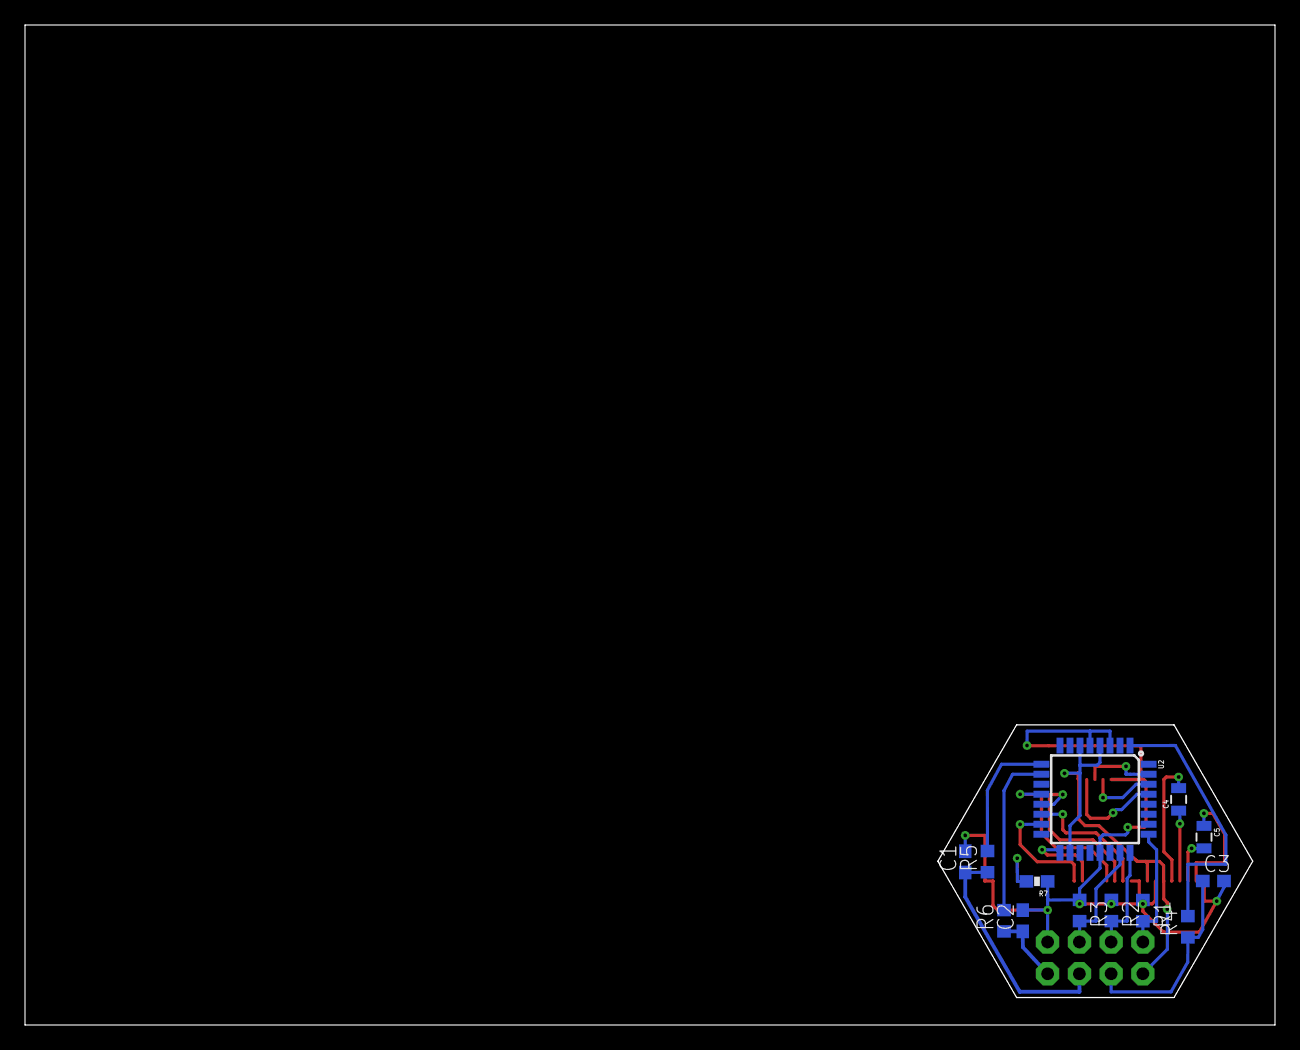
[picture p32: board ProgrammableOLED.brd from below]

Board: 2 copper layers, 100.0 x 80.0 mm, 16 parts (13 on the bottom side), 24 nets.

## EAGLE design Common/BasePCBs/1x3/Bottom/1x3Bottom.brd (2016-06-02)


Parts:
CON1, CON2, CON3, CON4, CON5, CON6: SHIELD_FINGER0820; SHIELD_FINGER_PKG
H1: M04; 1X04_NO_HOLES

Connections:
GND: CON4.P1, CON4.P2, H1.3
PWR: CON5.P1, CON5.P2, H1.2
SIN: CON6.P1, CON6.P2, H1.1
SOUT: CON1.P1, CON1.P2, CON2.P1, CON2.P2, CON3.P1, CON3.P2, H1.4


Board: 2 copper layers, 100.0 x 80.0 mm, 7 parts (0 on the bottom side), 4 nets.

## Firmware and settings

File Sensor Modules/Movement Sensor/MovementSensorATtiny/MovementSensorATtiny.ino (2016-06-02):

/*
**  MovementSensorATtiny.ino
**  MakerWear Movement Sensor Module's ATtiny Program.
**
**  Changes voltage output proportional to movement (higher voltage
**  means more movement has been sensed)
**
**
**  ATtiny Pin Configurations:  
**
**  Pin 1 (Reset): N/U                   Pin 8 (PWR):         5V
**  Pin 2 (D3/A3): Module Input          Pin 7 (D2/A1/SCK):   SCK
**  Pin 3 (D4/A2): N/U                   Pin 6 (D1/PWM/MISO): Module Output
**  Pin 4 (GND):   GND                   Pin 5 (D0/PWM/MOSI): SDA
**
**
**  Created on 12/22/15.
**  By Majeed Kazemitabaar
**
**  MakerWear Link:
**  Github Link:      github.com/myjeeed/MakerWear
**
*/

#include <TinyWireM.h>
#include <ATtinyAccMag.h>
#include <Vector.h>
#define BUFFSIZE 40
double ratio = 100.0; 

int output_pin = 1;
int input_pin = 3;                           //Pin 2 on ATtiny

int accel_x = 0;
int accel_y = 0;
int accel_z = 0;

Vector queue[BUFFSIZE];
int head = 0;
int tail = 0;

void qpush(Vector v)
{
  if(((tail+1) % BUFFSIZE) != head)
  {
    queue[tail] = v;
    tail = (tail+1) % BUFFSIZE;
  }
}

Vector qpop()
{ 
  if(head != tail){
    Vector returnItem = queue[head];
    head = (head+1) % BUFFSIZE;
    
    return returnItem;
  }
}

ATtinyAccMag sensor;

long timer = 0;   //general purpuse timer

// Reads x,y and z accelerometer registers
void Read_Accel()
{
  //read accelerometer data:
  sensor.readAcc();
  
  //shift left 4 bits to use 12-bit representation
  //set the correct signs
  accel_x = -1 * (sensor.a.x >> 4);
  accel_y = -1 * (sensor.a.y >> 4);
  accel_z = -1 * (sensor.a.z >> 4);
}

void InitializeAccelerometer()
{
  while(!sensor.init())
  {
    //ping();
    delay(250);
  }
  
  sensor.enableDefault();
  
  switch (sensor.getDeviceType())
  {
    case ATtinyAccMag::device_D:
      sensor.writeReg(ATtinyAccMag::CTRL2, 0x18); // 8 g full scale: AFS = 011
      break;
    case ATtinyAccMag::device_DLHC:
      sensor.writeReg(ATtinyAccMag::CTRL_REG4_A, 0x28); // 8 g full scale: FS = 10; high resolution output mode
      break;
    default: // DLM, DLH
      sensor.writeReg(ATtinyAccMag::CTRL_REG4_A, 0x30); // 8 g full scale: FS = 11
  }
}

void setup() 
{  
  InitializeAccelerometer();
  
  pinMode(output_pin, OUTPUT);
  
  timer = millis();
  delay(20);
}

void loop() 
{
    int input_val = map(analogRead(input_pin), 50, 975, 0, 1023);
  
  if(input_val < 0)
    input_val = 0;
  else if(input_val > 1023)
    input_val = 1023;


    //maintain a window of all recent (BUFF_SIZE) accelerometer read values
    Read_Accel();
    Vector v(accel_x, accel_y, accel_z);
    
    if(((tail+1) % BUFFSIZE) != head)
    {
      qpush(v);
    }
    else{
      qpop();
      qpush(v);
    }
    
    double meanx = 0, meany = 0, meanz = 0;
    double sdx = 0, sdy = 0, sdz = 0;
    double power = 0.0;
    
    //loop through the window and calculate the Mean    
    for(int i = 0; i < BUFFSIZE; i++){
       meanx += queue[i].x;
       meany += queue[i].y;
       meanz += queue[i].z;
    }
    
    meanx = meanx/BUFFSIZE;
    meany = meany/BUFFSIZE;
    meanz = meanz/BUFFSIZE;

    //loop through the window and calculate the Standard Deviation for
    //X, Y & Z separately. (e.g. SD of X = Sum((Xi-Mean)^2)/N )
    for(int i = 0; i < BUFFSIZE; i++){
       sdx += (queue[i].x-meanx) * (queue[i].x-meanx);
       sdy += (queue[i].y-meany) * (queue[i].y-meany);
       sdz += (queue[i].z-meanz) * (queue[i].z-meanz);
    }
    
    sdx = sdx/BUFFSIZE;
    sdy = sdy/BUFFSIZE;
    sdz = sdz/BUFFSIZE;

    power = (sdx + sdy + sdz)/ratio;
    
    if(power < 0)
      power = 0;
    else if(power > 1000)
      power = 1000;
      
    int output_val = map(power, 0, 1000, 0, input_val/4);
    
    //write output value:
    analogWrite(output_pin, output_val);
}

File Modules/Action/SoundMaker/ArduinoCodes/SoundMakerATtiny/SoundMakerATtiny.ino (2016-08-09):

/*
**  SoundMakerArduino.ino
**  MakerWear SoundMaker Module's ATtiny Program.
**
**  Similar to Piezzo Buzzer but a more melodic sound (far less cacophonous).
**  Plays a scale based on input level. If you hooked up more than one, you
**  could start to play chords. Instead (or in addition to) the piano, could
**  have other instruments like a saxaphone or flute. The key is it should 
**  sound nice to the ears in contrast to the piezo.
**
**
**  ATtiny85 Pin Configurations:  
**
**  Pin 1 (Reset): N/U                   Pin 8 (PWR):         5V
**  Pin 2 (D3/A3): Module Input          Pin 7 (D2/A1/SCK):   N/U
**  Pin 3 (D4/A2): N/U                   Pin 6 (D1/PWM/MISO): Buzzer
**  Pin 4 (GND):   GND                   Pin 5 (D0/PWM/MOSI): N/U
**
**  Programming Options (Arduino as ISP):
**  Bootloader: ATtiny85 @ 1MHz Internal Oscillator, BOD Disabled
**
**
**  Created on 8/10/15.
**  By Majeed Kazemitabaar
**  Last modified and tested on 6/21/16.
**  By Majeed Kazemitabaar
**
**  MakerWear Link:
**  Github Link:      github.com/myjeeed/MakerWear
**
*/

#include <SignalProcessing.h>
#include "Pitches.h"

//Pin Configurations
int input_pin = 3;                           //pin 2 on ATtiny
int buzzer_pin = 1;                          //pin 6 on ATtiny
int filter_size = 25;                        //Noise reduction filter size

SignalProcessing input(input_pin, filter_size);

void setup() 
{  
  pinMode(buzzer_pin, OUTPUT);
}

int state = 0;
int threshold = 18;

void loop() 
{
  int input_val = cutAndMap(input.filteredAnalogRead(AVERAGE), 50, 975, 0, 1023);

  if(state == 0 && input_val > 114 + threshold)
    state = 1;
  else if(state == 1 && input_val < 114 - threshold)
    state = 0;
  else if(state == 1 && input_val > 227 + threshold)
    state = 2;
  else if(state == 2 && input_val < 227 - threshold)
    state = 1;
  else if(state == 2 && input_val > 341 + threshold)
    state = 3;
  else if(state == 3 && input_val < 341 - threshold)
    state = 2;
  else if(state == 3 && input_val > 454 + threshold)
    state = 4;
  else if(state == 4 && input_val < 454 - threshold)
    state = 3;
  else if(state == 4 && input_val > 567 + threshold)
    state = 5;
  else if(state == 5 && input_val < 567 - threshold)
    state = 4;
  else if(state == 5 && input_val > 681 + threshold)
    state = 6;
  else if(state == 6 && input_val < 681 - threshold)
    state = 5;
  else if(state == 6 && input_val > 794 + threshold)
    state = 7;
  else if(state == 7 && input_val < 794 - threshold)
    state = 6;
  else if(state == 7 && input_val > 908 + threshold)
    state = 8;
  else if(state == 8 && input_val < 908 - threshold)
    state = 7;
    
  switch(state)
  {
    case 0:
      noTinyTone();
      break;
    
    case 1:
      tinyTone(Note_C, 6);
      break;

    case 2:
      tinyTone(Note_D, 6);
      break;

    case 3:
      tinyTone(Note_E, 6);
      break;

    case 4:
      tinyTone(Note_F, 6);
      break;

    case 5:
      tinyTone(Note_G, 6);
      break;

    case 6:
      tinyTone(Note_A, 6);
      break;

    case 7:
      tinyTone(Note_B, 6);
      break;

    case 8:
      tinyTone(Note_C, 7);
      break;
  }
}

void tinyTone(unsigned char divisor, unsigned char octave)
{
  TCCR1 = 0x90 | (8-octave); // for 1MHz clock
  //TCCR1 = 0x90 | (11-octave); // for 8MHz clock
  OCR1C = divisor-1;         // set the OCR
}

void noTinyTone()
{
  TCCR1 = 0x90;
}

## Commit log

2015-08-05 6 Modules added
    BarGraph, DistanceSensor, LightSensor, PianoSynthesizer, Pulse, RGB_LED
    The DistanceSensor is *NOT* updated with Tony’s latest version.
    [MetricConversion.xlsx]
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2015-08-11 Added the simple impact sensor
    This version of the impact sensor will only pass-through the input only
    for a short duration.
    [ImpactSensorATtiny.ino]
2015-08-11 fixed sound sensor folder
    [SoundSensorArduino.ino]
2015-08-11 Added buggy Sound Sensor
    [SoundSensorArduino.ino]
2015-08-11 Revert "Added buggy Sound Sensor"
    This reverts commit 7c292b2102d95ad7382008a5954522c9bad4a963.
    [SoundSensorArduino.ino]
2015-08-11 Added buggy SoundSensor
    It’s buggy :-|
    [SoundSensorArduino.ino]
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2015-08-13 Piano Tone off-notes fixed
    Used to jump from B to E, fixed it to jump from B to C
    [PianoSynthesizerATtiny.ino]
2015-08-15 distance sensor still not working perfectly :-(
    [MetricConversion.xlsx]
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2015-08-25 Added Vibration Motor's code
    [VibroMotorATtiny.ino, VibroMotorArduino.ino]
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2015-10-21 fixed bar-graph mixed pins
    many problems in the PCB can be fixed with the code, like this one :)
    [BarGraphATtiny.ino]
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2015-10-21 fixed Light Sensor
    The problem was in the pin number! ATtiny pin numbers and the internal
    pins are very confusing…
    [LightSensorATtiny.ino, LightSensorArduino.ino]
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2015-10-22 UV Light Sensor, fixed and tested on ATtiny
    [UVSensorATtiny.ino, UVSensorArduino.ino]
2015-10-22 fixed vibro motor
    TODO: needs testing
    [VibroMotorATtiny.ino]
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2015-12-22 UV Light Sensor
    The UV Sensor works perfectly fine on both Arduino and ATtiny85. TODO:
    Need to solve hardware issues (soldering? wiring? PCB?)
    [UVSensorATtiny.ino, UVSensorArduino.ino]
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2016-01-23 Impact Sensor
    changed the name from Vibration Sensor to Impact Sensor
2016-01-27 Color Sensor + RGB LED
    They both need to be updated to the 8 color / musical tone version
    [ColorMeans.xlsx]
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2016-03-23 Colorful Light
    there were some noisy color changes when switching from one color to
    another color, fixed that by making sure that the ranges are all
    continues.
    [RGBLEDATtiny.ino]
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2016-06-02 enhanced bargraph to look nicer!
    the first LED is no longer binary, and it would change its brightness
    based on the module’s input voltage.
    [BarGraphATtiny.ino, BarGraphArduino.ino]
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2016-06-02 using millis() instead of delay() for the pulse module
    so it would no longer lag, and be more responsive to input voltage
    changes.
    [PulseATtiny.ino]
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2016-06-02 Light sensor is responsive to the module's input
    (e.g. when nothing is connected to it such as a power source, it should
    not work. Or a potentiometer before it should set the highest output
    voltage of the Light sensor’s output as well).
    [LightSensorATtiny.ino]
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2016-06-02 still not working on ATtiny
    [SoundSensorATtiny.ino, SoundSensorArduino.ino]
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2016-06-02 added base line ATtiny code for the Thermal Camera sensor
    it does not work on the ATtiny, moving it to ATmega328
    [ThermalCameraATtiny.ino]
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2016-06-02 added ATtiny & ATmega base codes
    added the base folder for inheritance/modular development of new
    modules.
    [ColorMeans.xlsx, MetricConversion.xlsx]
2016-06-02 Revert "added ATtiny & ATmega base codes"
    This reverts commit 449d7c33cb42b075b19831fc93cc41e8839f986d.
    [ColorMeans.xlsx, MetricConversion.xlsx]
2016-06-02 Revert "Revert "added ATtiny & ATmega base codes""
    This reverts commit d113522cb5293a815a4a0bf3c465b4f46995ecc6.
    [ColorMeans.xlsx, MetricConversion.xlsx]
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2016-06-03 Revert "fixed #17"
    This reverts commit f6ba359138b2088bb300b65ffddfbec81b2abcc3.
    [LightSensorATtiny.ino]
2016-06-03 Revert "ImpactSensor: incorrect output value"
    This reverts commit 078d72130c4ec126aeb76cc266c4702d674c8590.
    [ImpactSensorATtiny.ino, RotatorATmega.ino]
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2016-06-11 added Counter Module
    added the base code for the new Counter Module. It is compatible with
    all action modules, especially Number and LightBar.
    [Counter.brd, Counter.sch]
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2016-06-11 fixed #27
    the white LED will only be switched ON when the module is receiving
    HIGH input voltage. This makes the module (and the white LED) to be
    controlled using a button that could come before the module.
2016-06-11 SingleLight: added gamma table
    corrected the brightness levels based on
    https://learn.adafruit.com/led-tricks-gamma-correction/the-quick-fix
    [SingleLightATtiny.ino]
2016-06-12 added dimensions
    the illustrator (.ai) files and their drawing (.dxf) exports that could
    be read by the ULF reader. Also added the ULF eagle library to import
    .dxf files into eagle.
    [0x6Connection.brd, 0x6Connection.sch, 0x6_bottom_bDoc.dxf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]
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2016-06-13 fixed the Fade module
    wasn't fading properly!
    [FadeArduino.ino]
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2016-06-13 Revert "Merge branch 'version-1.2'"
    This reverts commit 982d9c85d5bd00c48b539e840003de48d3cf178d, reversing
    changes made to b3895ae538c161df72313035d3e956c7a5ec4dbc.
    [0x6Connection.brd, 0x6Connection.sch, 0x6Top.brd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]
2016-06-13 Added Wire Module
    Added schematic and board files for both wire_send and wire_receive
    modules
    [wire_receive.brd, wire_receive.sch, wire_send.brd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]
2016-06-13 fixed eagle files for new modules
    SIN/SOUT was not correctly connected in them.
    [Number.brd, Number.sch, Receiver.brd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]
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2016-06-14 changed visible layers
    just for designing. this made it easier to design the multi-layer PCB
    with every other layer set to be invisible.
    [TemperatureReader.brd]
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2016-06-15 Fixed Number Module Pin Numbers
    [NumberATmega.ino, NumberArduino.ino]
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2016-06-15 Revert "Rotator Module: Changed Servo Pin Number in Arduino"
    This reverts commit 651288429148469b819eefab4301f134befe588b.
    [RotatorATmega.ino]
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2016-06-16 DIY: fixed dimensions #33
    [DIY.brd]
2016-06-17 added bootloader Arduino shields
    PCB files for Arduino Shields: ATmega328p SMD bootloader, ATtiny85 DIP
    bootloader/programmer.
    [ATmegaBootloader.brd, ATmegaBootloader.sch, ATtinyProgrammer.brd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]
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2016-06-17 added dummy module
    probably will not use this PCB though :)
    [Dummy.brd, Dummy.sch]
2016-06-17 changed 0403 cap to 0603 SMD cap
    to solder without difficulty!
    [Inverter.brd, Inverter.sch, VolumeKnob.brd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]
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2016-06-17 DIY Module: added version number #33
    and name on top of the PCB for documentation.
    [DIY.brd]
2016-06-17 added version numbers, and deleted most of the text that was on each module.
    [Number.brd, PulseSensor.brd, Receiver.brd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]
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2016-06-20 Corrected the Fade Module
    Did not work with the button at first. Also was not correctly using the
    LOW threshold.
    [FadeATtiny.ino, FadeArduino.ino]
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2016-06-20 Changed Schematic for ATmega programming shield
    Added switch so board can be used for programming the bootloader and
    normal programs
    [ATmegaBootloader.brd, ATmegaBootloader.sch]
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2016-06-22 Changed map function for vibration module
    Change range of map for output value to avoid "dead spot" when output to
    motor is close to zero
    [VibrationATtiny.ino]
2016-06-22 fixed #10
    - added gamma table to the first LED on the LightBar
    - added states/thresholds for switching between colors
    (MultiColorLight), steps (LightBar) and notes (SoundMaker)
    - changed input filter size to 25 on all of them (MultiColorLight was
    25 previously)
    [LightBarATtiny.ino, MultiColorLightATtiny.ino, SoundMakerATtiny.ino]
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2016-06-24 Fixed pulse sensor
2016-06-24 Fixed Number Module #48
    Made number module sync with count module, and added a threshold to
    prevent flickering between numbers
    [NumberATmega.ino]
2016-06-27 fixed minor comments/labels
    [ATmegaBootloader.brd, ColorDetector.brd, MotionDetector.brd]
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2016-06-27 TemperatureReader: added the range and tested it #31
    the range is: 32F - 150F (0C - 65C) we cannot have the range to be very
    large (as we won’t be able to see the significance of changes)
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2016-06-30 Number: removed crystal, modified for new bootloader #49
    also added resistor to make sure that we address #49
    [Number.brd, Number.sch]
2016-06-30 PulseSensor: removed crystal, and modified for new bootloader #40
    [PulseSensor.brd, PulseSensor.sch]
2016-06-30 Receiver: removed crystal, modified to work with new bootloader #29
    [Receiver.brd, Receiver.sch]
2016-06-30 Rotator: removed crystal, modified to work with new bootloader #30
    [Rotator.brd, Rotator.sch]
2016-06-30 Sender: removed crystal, modified to work with new bootloader
    [Sender.brd, Sender.sch]
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2016-07-01 DistanceSensor: added another IR-TX LED #9
    to increase the range of the module.
    [DistanceSensor.brd, DistanceSensor.sch]
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2016-07-06 Deleted stuff and renamed other stuff
    Deleted hybrid and triangle wave generators. Renames pulseMaker and
    SineWave to SquareGenerator and SineGenerator
    [SineGenerator.brd, SineGenerator.sch, SquareGenerator.brd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]
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2016-07-08 Decreased Threshold
    Fixed problem of skipping numbers
    [NumberATmega.ino]
2016-07-10 fixed Number module's digits
    [NumberATmega.ino]
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2016-07-10 Added one single Board Layout for WireSEND, WireRECV, and Dummy module
    it now has a small jumper that could be soldered in order to connect
    SIN to SOUT.
    [Dummy.brd, Dummy.sch, Wire.brd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]
2016-07-10 added pull-down resistor for Impact Sensor
    though we’re currently using the Tilt Sensor’s PCB for our current
    design.
    [ImpactSensor.sch]
2016-07-11 fixed pins on distance sensor
2016-07-11 Temperature Reader: Won't output when input is 0
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2016-07-12 fixed distance sensor code
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2016-07-14 DistanceSensor: fixed top cover's dimensions
    to work with 3 IR LEDs
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2016-07-22 Changed Fade
    potentiometer values were reversed
    [FadeATtiny.ino]
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2016-08-09 Changed SoundSensor codes
    we now use a different method of determining when there is only
    background noise.
    [SoundSensorATtiny.ino, SoundSensorArduino.ino]
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2016-11-07 added NRF24L01 based wireless modules
    The data will be sent to a computer for visualization and sensor-based
    programming by demonstration.
    [Wireless.brd, Wireless.sch]
2016-11-07 added old programmable module
    this is based on the
    https://www.seeedstudio.com/0.5-Inch-OLED-display-Arduino-shield-p-2194.
    html OLED display.
    The new version that I’m currently working on is based on the sparkfun
    OLED.
    [ProgrammableOLED.brd, ProgrammableOLED.sch]
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2016-11-08 trying to make the wireless sender module to communicate with a computer
    didn’t work :-/
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2016-11-15 Wireless Sender/Receiver: fixed their Arduino codes
    It now uses a single shared pipe for reading and writing.
    In the next version we will just have 6 nodes write into the same pipe.
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2016-11-15 added 3x3 Illustrator Dimensions, board schematics and layout
    to be used for the programmable module
    [3x3Top.brd, 3x3Top.sch, 3x3Top_outline(a).dxf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]
2016-11-15 updated the top PCB of the programmable module with a bigger PCB
    TODO: iterate and refine the top PCB
    [ProgrammableOLED.brd, ProgrammableOLED.sch]
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2016-11-29 updated the Programmable OLED PCB. now cleaner, need to go a final iteration on it
    [3x3Bottom.brd, ProgrammableOLED.brd]
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2016-12-02 updated the PCB/Schematics for the Gesture module
    TODO: now I only need to build the middle PCB (ATmega328p + IMU)
    [Gesture.brd, Gesture.sch]
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2016-12-05 moved MicroUSB more into the hexagon, removed holes for MicroUSB & OLED
    [ProgrammableOLED.brd, ProgrammableOLED.sch]
2016-12-05 increased rectangular copper widths to make it easier to fix/desolder
    [Socket.brd]
2016-12-05 another round of minor fixes
    [Gesture.brd, Gesture.sch, Programmable.brd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]
2016-12-05 fixed incorrect connections for the 3x3Bottom PCB
    [3x3Bottom.brd, 3x3Bottom.sch]
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2017-05-16 added the DIY module's PCB board
    it seems that it wasn’t here before! strange!
    [DIY.brd, DIY.sch]

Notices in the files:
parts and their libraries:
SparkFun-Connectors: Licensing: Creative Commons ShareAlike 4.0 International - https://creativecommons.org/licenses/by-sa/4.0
